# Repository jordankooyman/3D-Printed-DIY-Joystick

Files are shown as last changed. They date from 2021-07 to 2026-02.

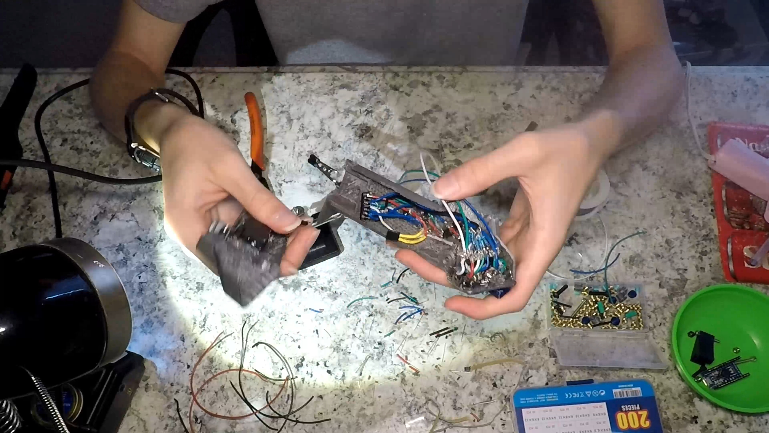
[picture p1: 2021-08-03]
Images/Pictures From Build Guide Video/Untitled_2.1.16.jpg

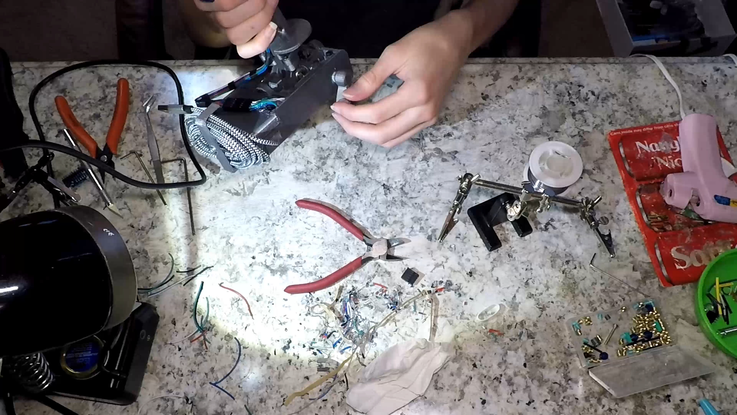
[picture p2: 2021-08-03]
Images/Pictures From Build Guide Video/Untitled_2.1.41.jpg

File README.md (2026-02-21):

# 3D-Printed DIY Joystick
A 3D-Printable Joystick for use with PC flight simulators
Throttle Joystick Side Videw

Updated!
New arduino code has been included in the code folder that should be much more reliable and easier to modify and work with.

This model uses hall-effect sensors for high accuracy inputs into flight simulators. The Joystick features 3 axes of movement (Pitch, Roll, and Yaw), and one potentiometer mounted in the base to act as a Throttle input (but it can be used as trim as well). 606 Bearings are used on the pitch and roll axes for smooth operation and longevity. A steel rod is used as the pivot point for the yaw axis. Due to the number of buttons included in the joystick (24), 3 8-bit shift registers are used to reduce the output wire count to a more reasonable number. Everything is connected to an Arduino Pro Micro, which uses an Atmega 32u4 processor, which is capable of handling USB communications without additional hardware or software. This means that although this joystick is custom-built, it is compatible with any PC that accepts USB Game Controllers (and maybe some consoles as well).

I have also created an optional Throttle-Assembly. To use it, a joystick can be mounted onto the sliding carriage on the Throttle-Assembly and a 3-pin-wire can be plugged into the joystick from the Throttle-Assembly, and a switch can be flipped on the joystick base to enable the external throttle input instead of the internal throttle input.

Overall, I spent about $175 on this project, but I had some of the parts on hand and I bought others in larger-than-necessary quantities. Depending on where and when your buy your parts  (and exactly what you intend to build), you overall cost will vary significantly.

-- This is NOT a beginner-friendly project as this is still an early prototype with some convoluted assembly --

# Credit Goes To:
Thingiverse user akaki for the original joystick model that I modified:		https://www.thingiverse.com/thing:4576634

Thingiverse user droftarts for their OpenSCAD pulley generator:				https://www.thingiverse.com/thing:16627

Thingiverse user Area51 for their GT2 Belt Clip:							https://www.thingiverse.com/thing:2354961

Matthew Heironimus for his Arduino Joystick library:						https://github.com/MHeironimus/ArduinoJoystickLibrary

Adafruit for their ADS11x5 Arduino Library which can be downloaded directly in the Arduino IDE

# Changes Made to Original Model
- The handle has been thinned drastically to allow for more space for the extra wires associated with 24 (instead of 6) buttons and 3 shift registers.

- The mounting pillar for the handle has been split with some wings added. The split allows the handle to be rotated in the yaw axis, and the wings allow for two arms to be mounted, with a spring in-between them to return the handle to 0 rotation.

- A hole has been cut in the bottom of the base to give additional clearance, as well as access, to the new yaw-axis hall-effect sensor.

- The front electronics section of the base has been doubled in length to give additional space for wiring as well as space for a 16-bit ADC (analog-to-digital converter) that is used in place of the 12-bit ADC built into the Arduino Pro Micro.

- 3 holes have been added to the front of the front cover peice to act as posts to wrap the usb cable around and to tie it in-place with. This is opposed to just wrapping the USB cable around the handle.

- All holes intended for M3 bolts have been enlarged to allow for Brass M3 Threaded inserts to be inserted to allow for better bolt pull-out resistance as well as increased longevity of the bolt threads.

- Most tolerances between parts increased to between 0.4mm and 0.6mm

- My Version D is a modification to akaki's Version C, so a number of my parts retain the Version C label as they have been changed minorly at most

# Code Configuration
The sample code is based on my right joystick code, which has one of the 4 hat switch inputs on the lower shift register. The reference code for the left joystick does not have this.
The same applies to the new V4.0 code as well. The new calibration process is very similiar to the old one, but it should be much more reliable and quicker.

# Print Settings
I used a 0.4mm Nozzle with PETG at 30% infill on most of the parts. The only exceptions are the Button Caps, which are so thin that a 0.2mm Nozzle is required, and the joystick left and right side, which are quite thin compared to the original and should probably be printed at around 60% to 80% infill.

Supports were enabled for all parts, but only touching the build plate. I used Cura's Tree Supports to reach most overhangs. Unless your support settings are tuned such that supports on top of printed parts peel off extremely easily, do not print supports on the parts, only on the build plate. Otherwise, you will likely need to use a rotary tool (such as a dremel) to remove them all.

I used Silver for most of the parts, with the Button Caps being printed in Translucent Aqua, and the trigger and Hat cover being printed in Translucent Glittery Dark Blue (called Starry Night).

# Joystick (Handle and Base) Bill of Materials
	1 Joystick:
	1 Arduino Pro Micro (Must have a ATmega 32u4 processor)(if pin headers are not already soldered in, I recommended soldering them to point up rather than down)
	1 ADS1115 (Optional: built in 12-bit ADC can be used instead)
	3 AH3503 Linear Hall-Effect Sensors
	1 15mm 10k 3 pin potentiometer with washer and nut
	24 10k Ohm Resistors (1 for each button, use a lower value is using active-low (button connects to ground) instead of active-high (button connects to VCC) button signals)
	2 4.7k Ohm Resistors (Optional: Only needed if using ADS1115 or similar board that uses I2C)
	3 74HC165 Parallel-to-Serial Shift Registers
	18 6mm*6mm Tactile Pushbutton Momentary Switches - Assorted button lengths
	1 SPDT Long Hinge Roller Arm Microswitch - Approximately 28mm*10mm*16mm
	1 10*10*9 6 pin 5-way Momentary Tactile Switch SMD (Optional) (A Nintendo Switch Replacement Joycon thumbstick might fit here instead (that would change the wiring fairly significantly, be aware)
	1 Micro USB to USB cable - Any length 4ft of longer
	1 5mm*65mm Steel Rod (Aluminum or Brass also acceptable)- Grind Flats as indicated in the 3D Model- Used as the Yaw-axis pivot
	2 M4*15 Socket-Head Bolt (Can be substituted for any M4 head variant)
	1 M4*15 Button-Head Bolt
	2 M4 Hex Nuts
	6 5mm*2mm round Neodymium magnets
	2 4pin*2pin Dupont-Style Connectors and assosiated crimpable pins (Precrimped wires can also be used) - Other connector styles can also be used
	2 M2*4mm Bolts (Optional: Only needed if installing external throttle input)
	17 Brass M3 Threaded Inserts - 6mm tall, 5mm diameter (use about 200 degrees C on soldering iron to press in)
	4 606 Bearings (any variant)
	1 3pin Dupont-Style Connector and 3 crimpable pins (Precrimped is also acceptable) - The pins and holes combination is arbitrary - (Optional: Only Needed if Throttle-Assembly is built)
	1 3 position slide switch - single pole (double pole also works) (Optional: Only Needed if Throttle-Assembly is built)
	Assorted M3 Bolts (6mm, 8mm, 10mm, 16mm, 25mm Recommended) Hex Socket Head recommended
	Assorted small extension springs (larger than pen springs, however)
	Pin headers for use with Arduino and ADS1115 (Optional)
	Wire of Assorted Colors (I used 22awg)
	Heatshrink of Assorted Sizes
	Thin Steel Sheet strips - Must be ferromagnetic (Can be obtained by cutting up the bottom of a Pringles can)
	5-minute Epoxy
	Isopropyl Alcohol
	Super Glue
	Disposable Rubber Gloves (Optional but recommended
	
	Rotary Tool (or some other way to cut steel (or your choosen metal shaft material))
	Mini Hot Glue Gun and Glue Sticks (Regular size also works, but not as easy to fit everywhere)
	Dupont-Style Crimping Tool
	Soldering Iron
	Tip for Soldering Iron that fits in the M3 inserts without sticking out the other end - expect to get plastic on this
	Wire Strippers (Optional, but highly recommended)
	Multimeter with continuinty testing (Optional, but highly recommended)
	~400g of filament
	
   # Printed Parts - Joystick
	Base (Version D):
		1 axis_for_ver_D v3  --  Print Flat
		1 base_cover  --  Print Front-Down
		1 Bottom  --  Print with wings down
		1 cable cap  --  Print Vertical, longest continuous side down
		1 cam_arm  --  Print Flat
		1 hinge_cam  --  Print Flat
		1 hinge_cam_slider_for_ver_C v3  --  Print Flat
		1 hinge_ver_D_-_606_bearings v3  --  Print Flat
		1 Mount Base  --  Print Bottom-Down
		1 Top  --  Print Tall with lengthwise hole facing up
		1 trim knob (Optional)
		1 Wire Storage Clip or Wire Storage Clip Hook (Optional)  --  Print Flat
		1 Yaw Rod Retention Clip  --  Print Flat
		2 Yaw Spring 2  --  Print Flat
		2 M4 Bearing Spacers  --  Print Flang-Down
	
	Handle:
		1 5-way button spacer (Optional)
		6 Button Cap Body - Print with 0.2mm Nozzle - Print Spares  --  Print Opening-Up
		12 Button Cap Face - Print with 0.2mm Nozzle - Print Spares  --  Print Opening-Up
		1 Face Plate  --  Print Rounded-Edge-Down
		1 joystick_grip_left_side v2 - with Left Side Handle Insert lined up, as seen in joystick grip left side filled.3mf  --  Print with hollow inside down
			- Mirror this part to make a left handle instead of a right handle
		1 joystick_grip_right_side v2  --  Print with hollow inside down
			- Mirror this part to make a left handle instead of a right handle
		1 Stadium Hat or Trim Hat  --  Print with short stem down
		1 trigger  --  Print Side-Down

# Throttle-Assembly Bill of Materials: - Requires Joystick to Use
	2 8mm*330mm Steel Rods - must be perfectly straight
	4 8mm*15mm*45mm Linear Bearings (shorter bearings are also compatible, and only 2 are necessary, but Mount will need to be redesigned)
	4 606 Bearings (any variant)
	1 15mm 10k 3 pin potentiometer with washer and nut
	3 3mm*300mm Steel Rods (other metals also acceptable) (Optional: Recommended, but not needed if base is printed in 2 pieces)
	1 1m GT2 Timing Belt
	16 Brass M3 Threaded Inserts - 6mm tall, 5mm diameter (use about 200 degrees C on soldering iron to press in)
	2 M3*35mm Bolts
	10 M3*10mm Bolts
	10 M3 Washers
	12 5mm*2mm round Neodymium magnets
	8 small zipties
	1 70mm Closed Loop MXL Belt - Can be subsituted for another type of belt, ideally a closed loop of about this length or slightly longer
	Masking tape
	5 minute epoxy
	Isopropyl Alcohol
	Grease (for the linear bearings)
	Disposable Rubber Gloves (not necessary, but recommended)
	
	Rotary tool (or some other way to cut the 3mm metal rods to 80mm lengths (7 are needed))
	Mini Hot Glue Gun and Glue Sticks (Regular size also works, but not as easy to fit everywhere)
	Dupont-Style Crimping Tool
	Soldering Iron
	Wire Strippers (Optional, but highly recommended)
	Multimeter with continuinty testing (Optional, but highly recommended)
	Tip for Soldering Iron that fits in the M3 inserts without sticking out the other end - expect to get plastic on this
	~600g of filament
	
   # Printed Parts - Throttle Assembly
	Fit Test:
		1 Base - Ensure the 8mm*330mm Steel Rods fit  --  Print with hole horizontal
		1 Mount - Ensure the 8mm*15mm*45mm Linear Bearings Fit
	Build:
		4 Adjustable Bearing Pillow Block v2  --  Print Side-Down
		1 Adjustable Pot Mount  --  Print Potentiometer-Hole-Horizontal
		1 Base 1  --  Print Flat
		1 Base 2  --  Print Flat
		1 Cover 1  --  Print Flat
		1 Cover 2  --  Print Flat
		1 Belt Pin Spacer  --  Print Flat
		1 Drive Axle  --  Print Flat-Side-Down
		1 Idler Axle (lower into print bed to create a flat side for better printing reliability)  --  Print Flat
		1 Mount  --  Print Top-Down
		1 Mount Side  --  Print Tab-Up
  	Imported Parts:
		2 X-Belt-Holder-Thin-GT2  --  Print Vertical
		2 GT2 2mm 6mm Wide 50 Tooth Idler M4 Shaft  (Sample - Generate and Test your own to ensure they fit your belt and Drive Axle and Idler Axle)  --  Print with teeth vertical
		1 40T 2.75mm MXL Pulley for Pot  (Sample - Generate and Test your own to ensure they fit your belt and potentiometer)  --  Print with teeth vertical
		1 20T 2.75mm MXL Pulley  (Sample - Generate and Test your own to ensure they fit your belt and Drive Axle)  --  Print with teeth vertical
				Use the OpenSCAD pulley generator for these 4 pulleys, using about the same size for all and the 2:1 gear ratio for the potentiometer. More drastic changes will require the model to be reworked.

# Build Guides:
Check out the videos I made for the major steps of the build as well as tips while building.

Check out the BuildSteps.md file for more step-by-step instructions without pictures. Reference the video to see pictures of all major steps.

Check out my Calibration Guide video to learn how to calibrate your own joystick using the code I wrote. Some aspects of the calibration process has been updated since the video, check the comments at the top of the sample code for details.
	
* Use the Sample Code provided and modify as needed to test and program your Arduino Pro Micro(s) for your joystick(s)
	
	* My Joysticks' code is included for reference purposes only and is not written to be modified as easily, nor is as well documented

# Project Videos:
Project Overview:													https://youtu.be/e_4dbrvhuwY

Chair Mounting Solution and Throttle-Assembly Build Explanation:	https://youtu.be/rQSjNkJ6G9A

Joystick Approximate Build Guide:									https://youtu.be/sCnEafJgWUY

Joystick Calibration Guide (Outdated):							https://youtu.be/MGDJYMHP4_0

Full Build Timelapse (5x Real Speed):								https://youtu.be/Amg51pNDD08

# Elite Dangerous Sample Gameplay Videos Using My Joysticks:

Bounty Hunting:									https://youtu.be/YqyOV4E18Ls
	
Mining:											https://youtu.be/bz7r8q-hPg0
	
Traveling Between Systems:						https://youtu.be/_PC3MqTWRCQ
	
- Vulture Ship Outfitting (bounty hunting):		https://youtu.be/YhuHz4nPciU
	
- Anaconda Ship Outfitting (mining):			https://youtu.be/gqCUKOQVyXI

# Future Ideas:
- Redesign the handle from scratch with a slightly increased diameter, larger face plate, and reworked thumb section for more wiring space and more strength.

- Add more buttons to the handle by adding a fourth shift registers

- Connecting all shift registers to one communications set instead of two seperate communications sets (this requires a decoupling capacitor to function)

- [Optional] Change the hat switch out for a Joycon thumbstick - likely connected to the Arduino Pro Micro's 12-bit ADC (should need two inputs)

- Improve the cable storage technique 

- Design a standalone handle with some buttons and an Arduino Pro Micro to mount on the throttle assembly and use it without a Joystick connected

- Design a function pedal unit that uses an Arduino Pro Micro - or hooks into the external potentiometer connector on a joystick - must be stable enough to use - anchor to chair?

- Rework the front cover part to clip in instead of glue in

- Design a custom PCB(s) for the face buttons - include the option for a few different layouts (such as using a joycon part over hat switch) - potentially use a large connector to join all buttons onto handle PCB and include shift registers there instead(?)

- Design a custom PCB for the handle - likely using short extension wires for each button

- Use a 10K Ohm Resistor Array (9 pin, bussed) for each shift register on a PCB (and try to avoid SMD components so all can be hand soldered easily)

- Design a custom PCB for the Joystick Base electronics section (with the ability to use an auxiliary ADC, or use internal ADC (and trim board shorter??))

- Improve the ribbon cable that joins the joystick handle and base (more flexibility and durability)

- Improve the external throttle connection location (as well as the slide switch)

- Revise throttle sensing mechanism to be more robust and simpler while maintaining long travel and absolute positioning with 0.1mm accuracy

- Improve Yaw axis mounting (move inside handle)

- Revise Yaw return-to-center with pair of torsion springs inside, longer fixed shaft with bearings, and a printed part on top with set screw to attach top bearing and springs and magnet to

- Simplify Build Guide and add a picture to each step

- Redesign code architecture to allow for dynamic callibrations to be generated and stored using a PC utility

- Improve resolution of hall sensor readings to allow for smoother movement when range is cropped

- Improve hall sensor mounting and wiring on pitch/roll axes

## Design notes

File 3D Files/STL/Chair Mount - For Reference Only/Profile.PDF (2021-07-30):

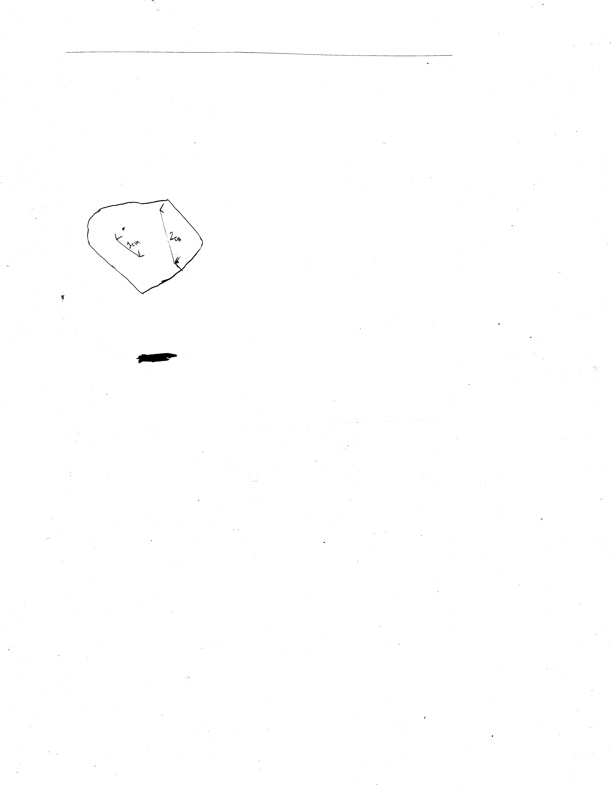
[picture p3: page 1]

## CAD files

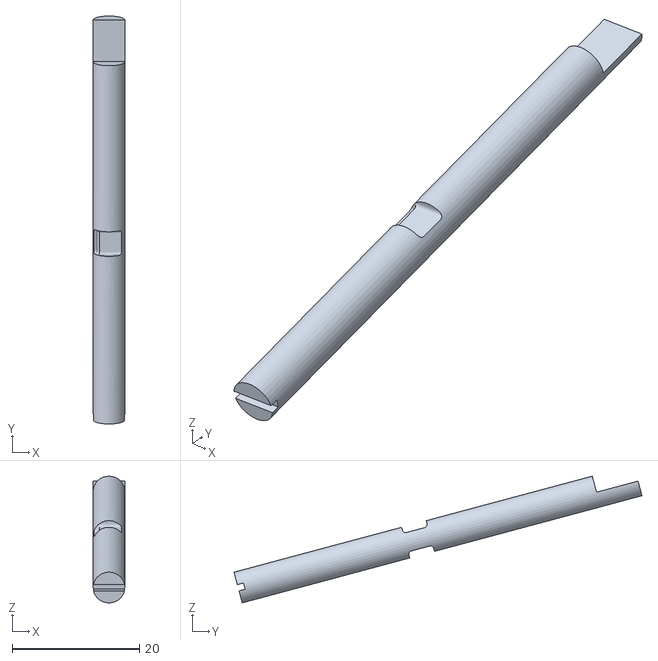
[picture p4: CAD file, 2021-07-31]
3D Files/STL/Base - Version D/Yaw Shaft (Steel).stl
4.99 x 64.1 x 19.9

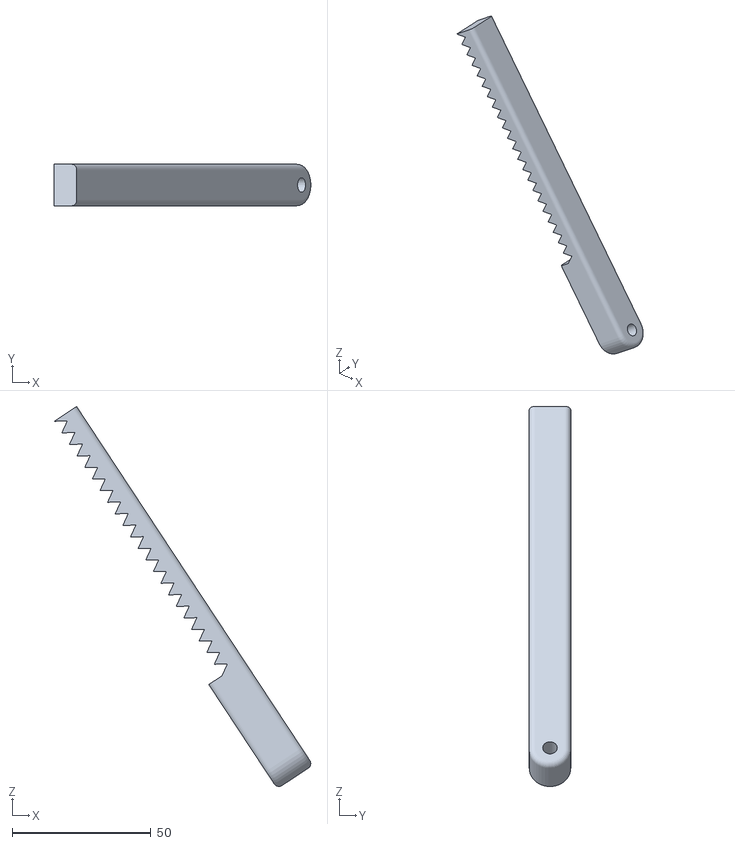
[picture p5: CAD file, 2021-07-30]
3D Files/STL/Chair Mount - For Reference Only/Long Support Arm Top.stl
92.6 x 15.0 x 137.1

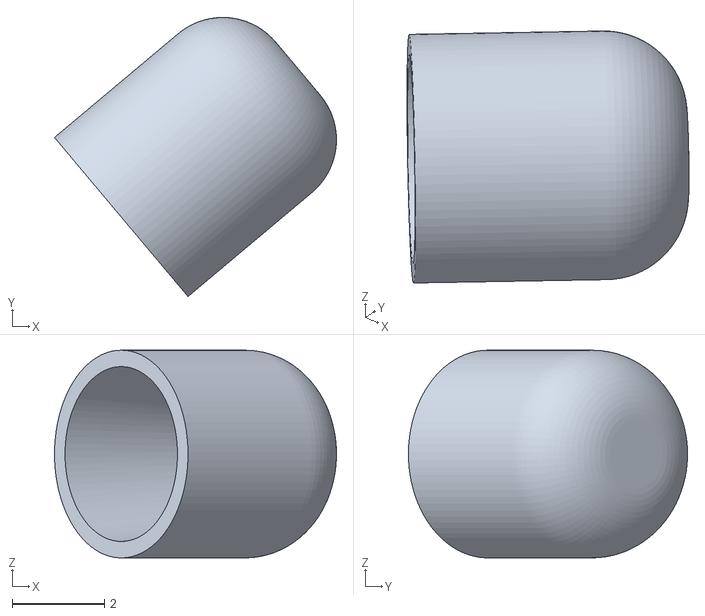
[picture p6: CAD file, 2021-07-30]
3D Files/STL/Handle/Button Cap Face.stl
6.11 x 6.05 x 4.50

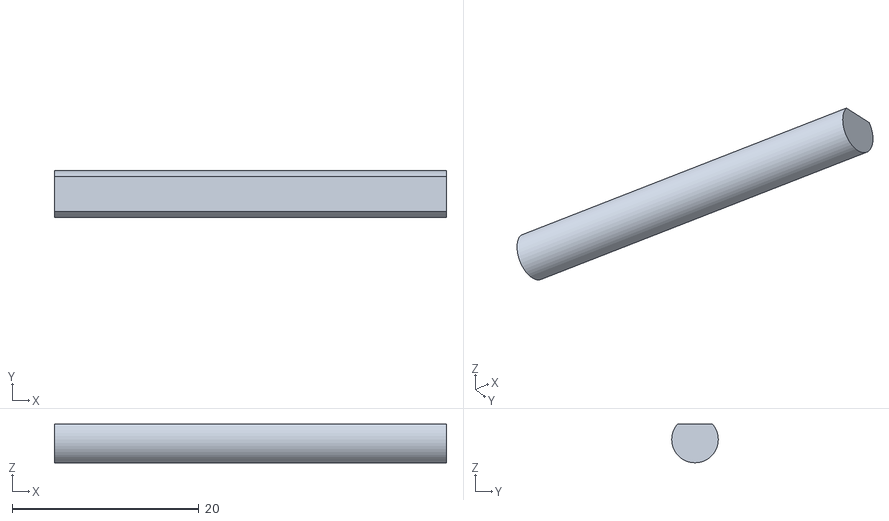
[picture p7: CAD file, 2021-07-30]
3D Files/STL/Throttle Add-On 2.0/Drive Axle.stl
42.0 x 5.00 x 4.14

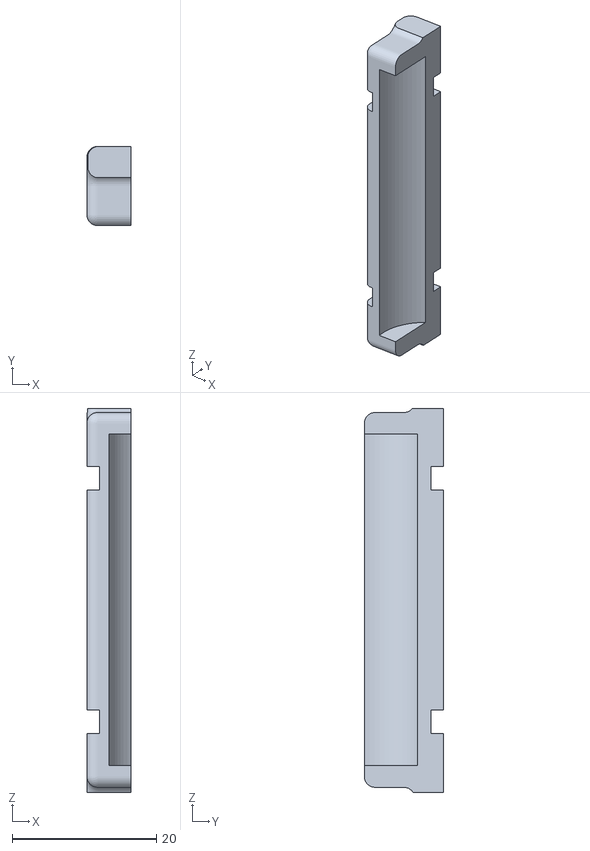
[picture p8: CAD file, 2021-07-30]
3D Files/STL/Throttle Add-On 2.0/Fit Test/Mount.stl
6.14 x 11.0 x 53.3

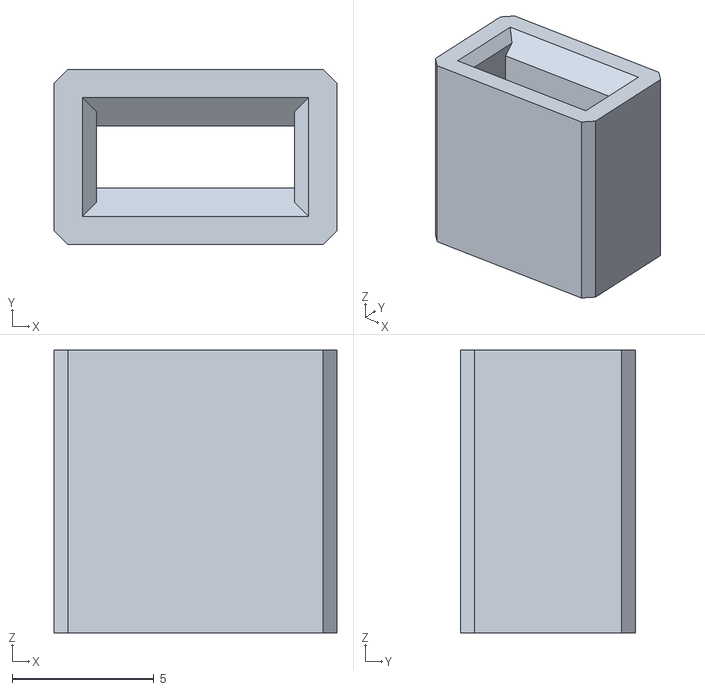
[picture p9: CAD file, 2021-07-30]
3D Files/STL/Throttle Add-On 2.0/Imported Parts - Sample Only/X-Belt-Holder-Thin-GT2.stl
10.0 x 6.20 x 10.0

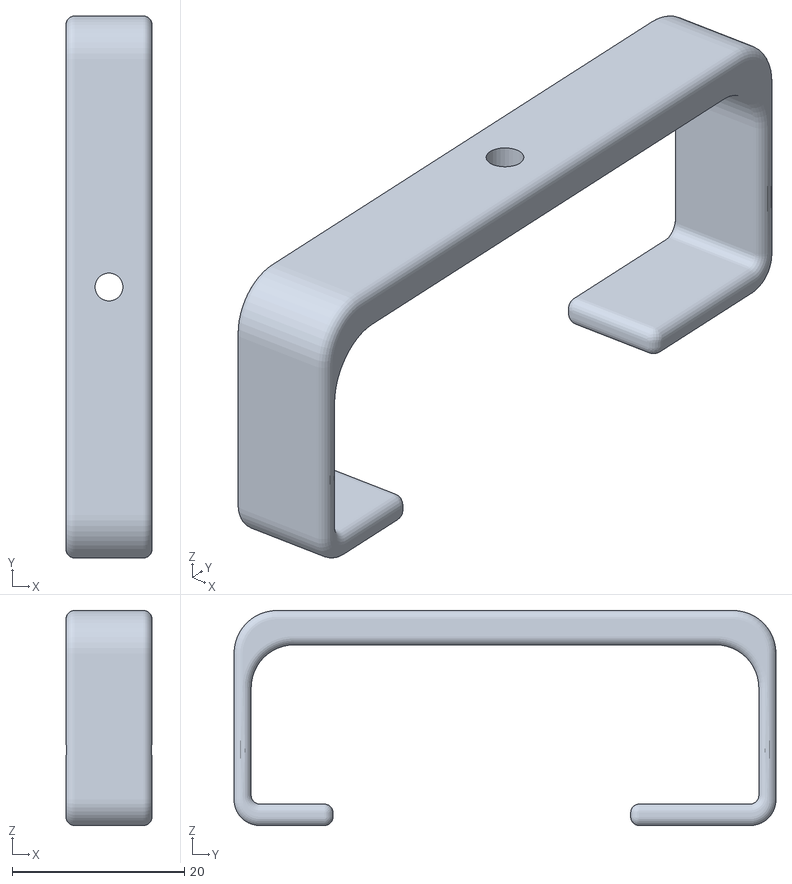
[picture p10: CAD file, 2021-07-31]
3D Files/STL/Base - Version D/Wire Storage Clip Hook.stl
10.0 x 63.0 x 25.0

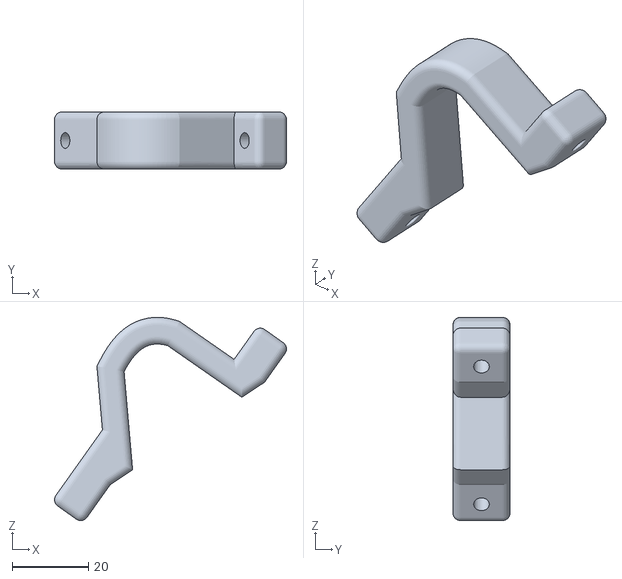
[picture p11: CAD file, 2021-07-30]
3D Files/STL/Chair Mount - For Reference Only/Left Clamp Back Top.stl
60.9 x 15.0 x 53.3

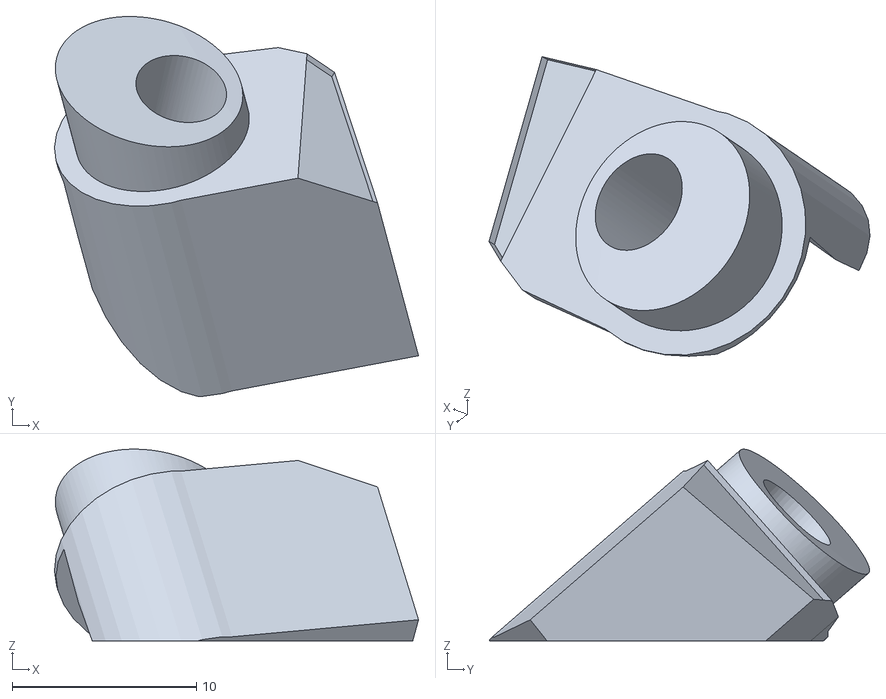
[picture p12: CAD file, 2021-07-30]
3D Files/STL/Handle/Left Side Handle Insert.stl
19.8 x 20.6 x 10.4

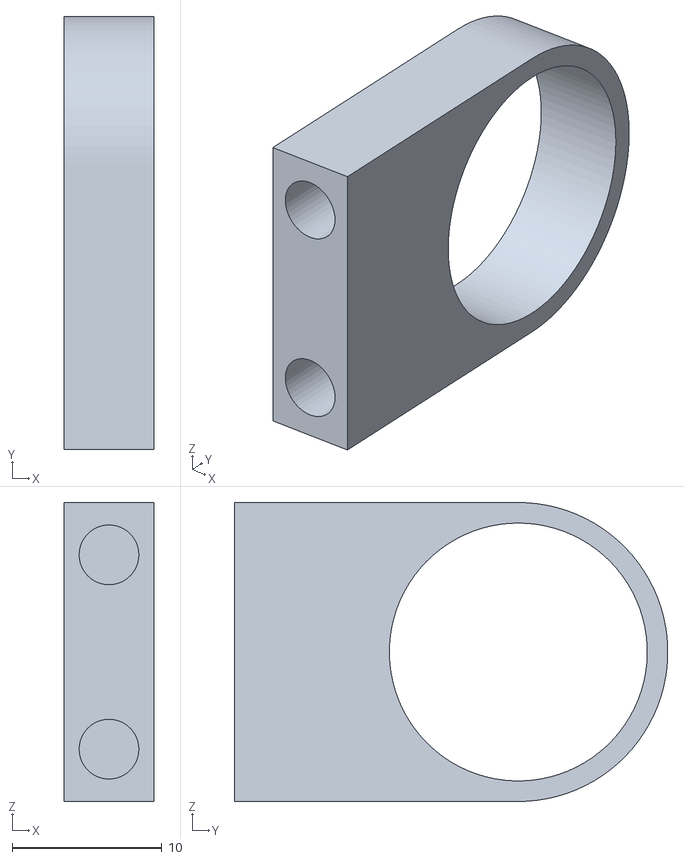
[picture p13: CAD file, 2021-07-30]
3D Files/STL/Throttle Add-On 2.0/Adjustable Bearing Pillow Block v2.stl
6.00 x 29.0 x 20.0

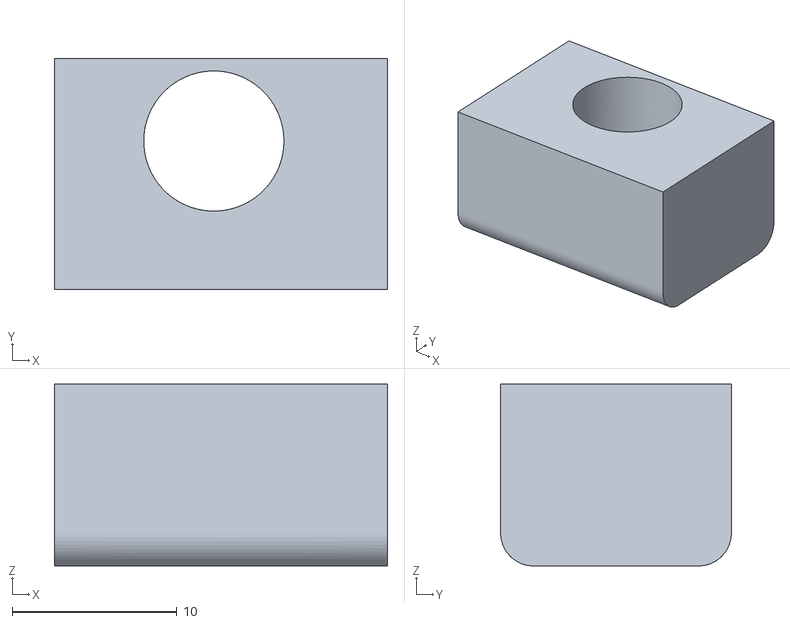
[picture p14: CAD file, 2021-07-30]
3D Files/STL/Throttle Add-On 2.0/Fit Test/Base.stl
20.2 x 14.0 x 11.0

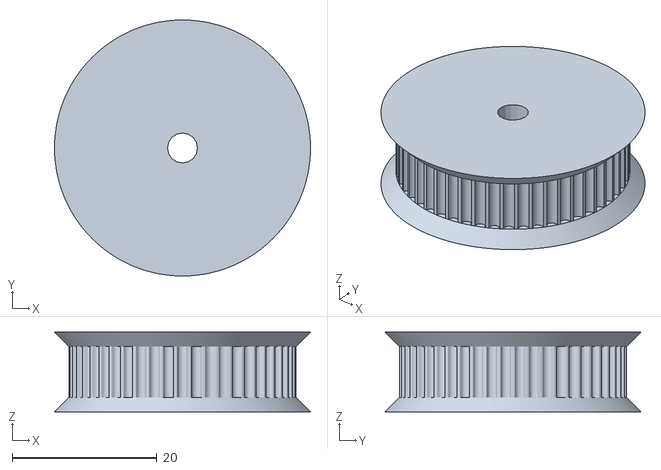
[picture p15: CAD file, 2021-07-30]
3D Files/STL/Throttle Add-On 2.0/Imported Parts - Sample Only/GT2 2mm 6mm Wide 50 Tooth Idler M4 Shaft.stl
35.3 x 35.3 x 11.0

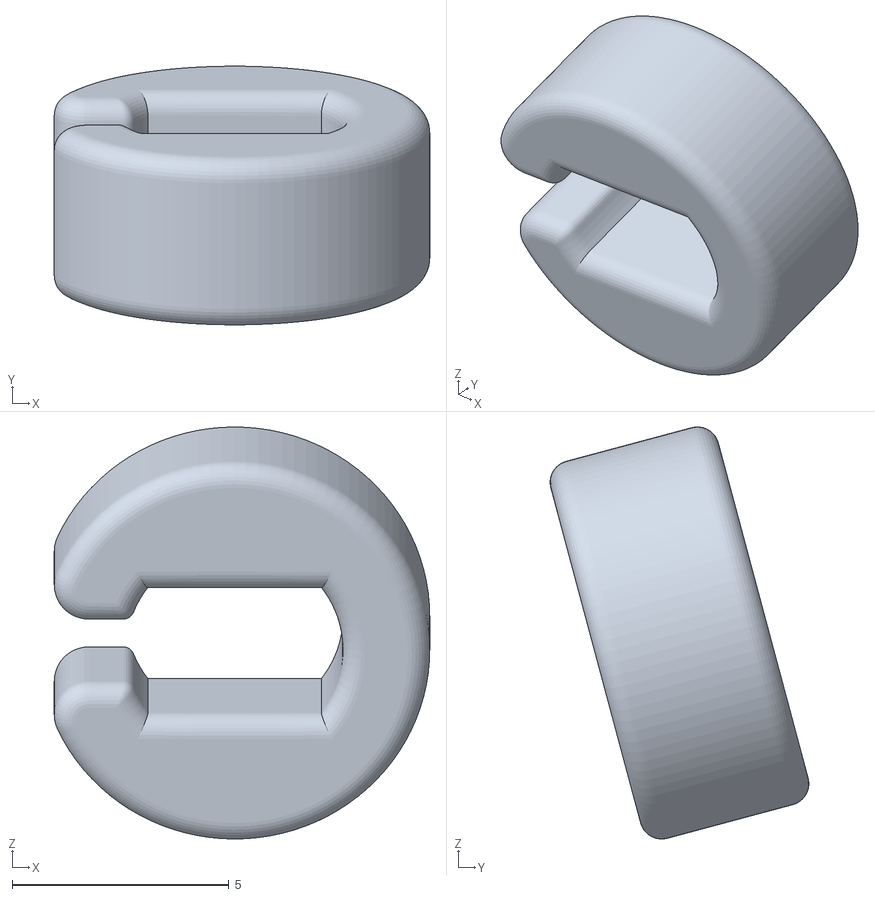
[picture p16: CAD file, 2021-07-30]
3D Files/STL/Base - Version D/Yaw Rod Retention Clip.stl
8.66 x 5.96 x 9.50

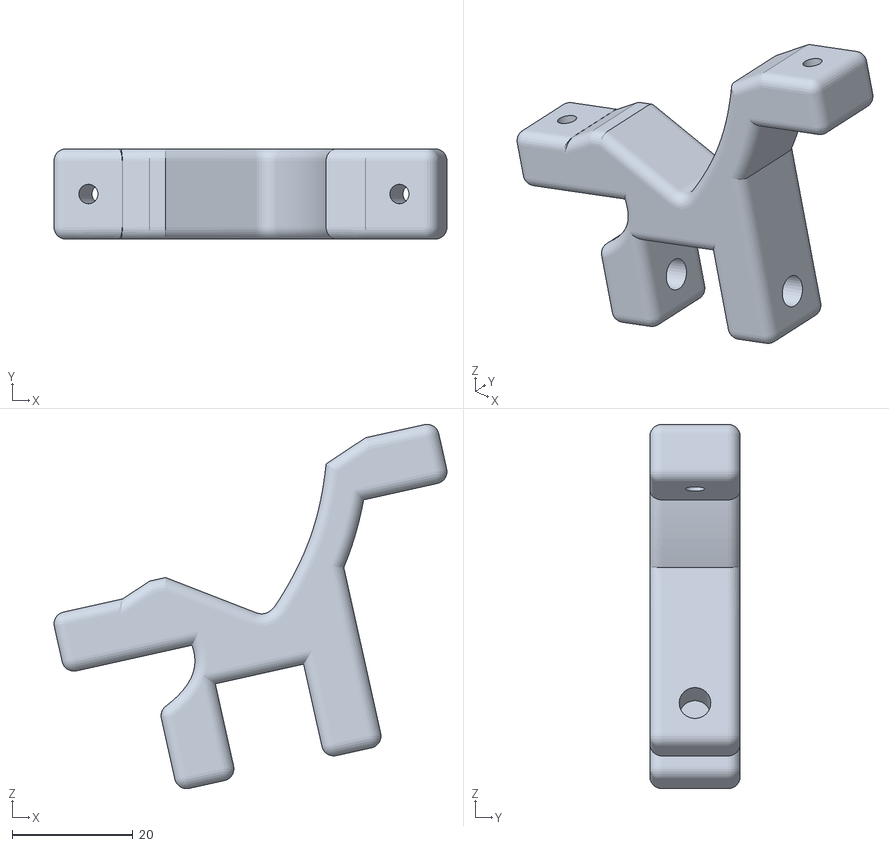
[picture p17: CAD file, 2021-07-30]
3D Files/STL/Chair Mount - For Reference Only/Right Top Front Clamp.stl
65.2 x 15.0 x 60.5

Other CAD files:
3D Files/STL/Handle/5-way button spacer.stl
3D Files/STL/Throttle Add-On 2.0/Cover 1.stl
3D Files/STL/Throttle Add-On 2.0/Imported Parts - Sample Only/40T 2.75mm MXL Pulley for Pot.stl
3D Files/STL/Base - Version D/cable cap.stl
3D Files/Fusion 360/Custom Chair Mount (Reference Only).f3d
3D Files/STL/Base - Version D/Bottom.stl
3D Files/STL/Base - Version D/M4 Bearing Spacer.stl
3D Files/STL/Base - Version D/Mount Base.stl
3D Files/STL/Base - Version D/Top.stl
3D Files/STL/Base - Version D/Wire Storage Clip.stl
3D Files/STL/Base - Version D/Yaw Spring 2.stl
3D Files/STL/Base - Version D/axis_for_ver_D v3.stl
3D Files/STL/Base - Version D/base_cover.stl
3D Files/STL/Base - Version D/cam_arm.stl
3D Files/STL/Base - Version D/hinge_cam.stl
3D Files/STL/Base - Version D/hinge_cam_slider_for_ver_C v3.stl
3D Files/STL/Base - Version D/hinge_ver_D_-_606_bearings v3.stl
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

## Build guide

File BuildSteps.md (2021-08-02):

This guide assumes you are building what I have built (including active-high button signaling)

# Joystick Build Instructions
Handle:

- Choose 12 6mm*6mm push buttons for the face panel (differing lengths can be used to make certain buttons stand out) and fit one button cap (shorter variant) to each one. If one does not stay on, a small dab of hot glue will help.

- Check the fit of the hat switch with hat included in the face plate. All 5 clicks should be accessible. If they are not, either change the spacing between the hat switch and face plate, or enlarge the hole. Once fit is good, glue in the spacer (if used) with a thin glue such as super glue, then continue.

- Arrange the 12 buttons in the face panel assembly such that one side of each button forms a common link with the buttons adjacent (the longer the chains, the less wires will be needed to join these together on the common side). Check which sides of the button are joined and which are only connected when the button is pressed (there are typically 4 pins, with 2 bars separating the 4 pins into 2 sets, and each set is joined together). Use hot glue to fill the gaps between the buttons to hold everything in place. Ensure enough space is left for the hat switch (or the spacer is glued in).

- Bridge one side of all the push buttons, using short lengths of red wire where necessary to form the common 5V line.

- Test the fit of this assembly in the both sides of the handle. Make any adjustments necessary for a good fit when the handle halves are held closed.

- Solder ~2 inch (50mm) lengths of different colored wires (not red or black) to all the buttons, one to each button. Ensure none of them are on the common side.

- Prepare the hat switch by tinning the 6 leads, measuring out and cutting 6 wires (1 color: ~8 inch (~250mm),4 colors: ~2.5 inch (~65mm), red: ~1 inch (~25mm)). Connect the red wire to the common pin, the long wire to the center click pin, and the remaining wires to the remaining pins. Solder the wires such that each wire runs across the back of the hat switch, forming a V of inter-woven wires.

- Place the hat switch in its position and ensure it still fits with hat cover on. Then tack in with a small amount of hot glue before putting globs of hot glue all around it to hold it in place (ensure it can still move freely before and after the globs of hot glue are added. If it cannot, remove the hot glue by using isopropyl alcohol (pour small amounts around the edge of the glob and peel the hot glue off).

- Prepare 2 SN74HC165 Shift Registers by tinning all the leads that are needed (VCC, GND, 8 Inputs, Clock, Enable, Load Data, Serial Output, and Serial Input (only this one on 1 of the 2)). Find a wiring diagram online to determine which pins are what.

- Separate the 17 wires from the buttons into 5 groups: 1 group of 1 wire (the long wire from the hat switch) and 4 groups of 4 wires (try to keep each group to one line of buttons as best as possible and filling in gaps with the hat switch leads, as this makes soldering to the shift registers, and later debugging any issues, much easier). Trim each group of wires to a common length, ensuring they are all long enough to connect to an input pin on a shift register placed above it, upside down, strip ~3mm off each wire, and tin the end of each wire.

-  Continue by soldering in both shift registers to the button leads. Start with the middle 2 groups, connecting one to each shift register, then solder the outer 2 groups of wires to the outward facing inputs on each shift register.

- Connect a short length of red wire from the VCC input of each shift register to somewhere along the common path on the buttons.

- Cut a large diameter piece of heat shrink (ideally about 0.875 inches (~20mm) tall when flattened) to a length of ~1.5 inches (~30mm) and place between the 2 shift registers to prevent short circuits (do not unfold to 1 layer unless you do not have a large enough piece of heat shrink tubing).

- Test the fit of this assembly in the both sides of the handle. Make any adjustments necessary for a good fit when the handle halves are held closed.

- Prepare 16 10k registers by trimming one side to ~10mm and tinning the shortened leads.

- Solder the shortened end of each resistor to one input pin for all input pins on all shift registers. 

- Then do a half twist of all the long resistor leads above each shift register and separate out and bend one lead to go down to the GND pin and one lead to go to the Enable pin on each shift register, soldering them in place. 

- Then solder each ball of resistor leads together with a large blob of solder, followed by trimming all excess resistor leads. Then solder in a short length of black wire between the two solder balls.

- Connect the serial output of one shift register to the serial input of the other shift register (the one with that lead already tinned, preferably) with a short length of wire running along the bottom (now top) of the IC casing, staying under the resistors.

- Prepare 3 ~6 inch (~150mm) lengths of colored wire and connect one to each of the following pins on the shift register that has the serial input used: Load Data, Serial Output, and Clock. 

- Then, using a short length of the same colors of wire, connect the corresponding pins on the other shift register to this shift register and the pins with the long wires connected to it. 

- Write down which color of wire is connected to which pin.

- Connect a ~3 inch (~80mm) red wire to the common section of the buttons and a ~6 inch (~130mm) black wire to one of the solder balls.

- Test the fit of this assembly in the both sides of the handle. Make any adjustments necessary for a good fit when the handle halves are held closed.

- Test that everything is working by connecting all 6 wires to an Arduino Pro Micro (ideally using a single pin header) (red to VCC, black to GND, and the 4 colors to any I/O pin). Using the shift register test Sample code, test that every button works properly by updating the pin numbers to reflect which pins are used. Additionally, test this assembly again while it is pressed into both halves of the handle.

	- If a button is not giving an input, make sure the wire corresponding to has not come loose. If a button is showing as clicking multiple buttons, verify it is not shorting against other pins. If a button is showing as always on, make sure the wire for that button is not connected to the common side.

- Once everything is verified to be working, set this button panel assembly aside to begin working on the handle assembly.

- Begin by selecting 6 6mm*6mm push buttons of varying lengths, one for each hole in the primary side of the handle (left for right joystick, or right for left joystick). Ensure that each button can be clicked with a button cap (longer variant) pressed or glued to the end.

- Continue by tinning all 4 leads of all 6 buttons, then soldering a common red wire between all 6 (ensuring it is the proper length to reach each button when all are installed) and a colored wire that is long enough to reach slightly into the indent used for mounting the handle to the base. Additionally, ensure that the colored wires are not connected to or shorting against the common wire in any location (a continuity check works well).

- Solder an additional ~3 inch (~75mm) red wire to the common side of the furthest down button. Repeat this step for the button just above that (lowest) button.

- Once all the wires are soldered to all 6 handle buttons and all the buttons are fitted into the handle, apply a generous sized glob to the back of each button to hold it in place. Once the glue has cooled, ensure all buttons can still be pressed easily (if not, try twisting them or dropping a small amount of isopropyl alcohol down the button shaft and twisting it).

- Set the primary handle side aside to work on the secondary side.

- Prepare the large microswitch by soldering 2 ~2 inch (~25mm) wires to it, one to the common (this is ideally red), and a color to the normally open pin on the microswitch.

- Using the trigger, a long M3 Bolt (nut optional but useful), and the microswitch, determine the position of the microswitch such that the trigger can easily click the microswitch, the spring of the microswitch pushes the trigger back out entirely, and when the trigger is not pressed, the microswitch is also not clicked. Once that position has been found, use hot glue to hold the microswitch in position by applying hot glue around the 3 edges that do not have the button and lever arm (also, ensure that the hot glue does not impede the movement of the lever arm in any way).

- Then, bend the two wires soldered to the microswitch 180 degrees to come back alongside the side of the microswitch, trim the two wires to be even (in the bent shape) about 10mm from the upper edge (the side the lever arm overhangs) of the microswitch, place a short length of heat shrink tubing of appropriate size on each wire, slide the heat shrink as far down as possible, solder the two wires to a 2-pin pin header (or some other 2 pin connector), and insulate the solder joints with the heat shrink tubing. A small dab of hot glue can be used on one of the wires to help keep them bent around the microswitch, just ensure the connector has enough freedom of movement to reach to the other side of the joystick handle when closed up (with some extra movement if possible, as this makes final assembly and maintenance much easier).

- Set aside the secondary handle side and return to working on the primary handle side

- Now prepare the third shift register by tinning the pins being used (8 inputs, Clock, Enable, Load Data, Serial Output).

- Next, using the shift register (again, with pins pointing up the handle)  as reference, trim all wires (excluding the further up red wire) to be about ~5mm to ~10mm longer than necessary to connect to an appropriate pin (either input of VCC). Tin the wires and solder all wires in place. There should be 2 unused input pins, preferably on the outward facing side of the shift register.

- Now, using the secondary side as reference, bend the extra red wire from the primary side around until in lines up with the connector from the trigger microswitch, trimming off excess if needed (ensure some wire is left to allow for movement). Then, setting the secondary side to the side again, measure out a length of colored wire to reach from the end of the red wire down to an available shift register pin, giving extra length to follow any bends in the red wire and to reach the shift register in the flattest possible path. Then prepare the end of the red wire and both ends of the colored wire for soldering by stripping them and tinning them, as well as putting short lengths of heat shrink tubing on both.

- Solder the other end of the 2-pin pin header (used with the microswitch) to the red wire and colored wire, then slide up and shrink the heat shrink tubing. Additionally, solder the other end of the colored wire to an input pin on the shift register.

- Prepare 8 more 10k registers by trimming one side to ~10mm and tinning the shortened leads.

- Solder one resistor to each input pin, just as was done on the face button assembly. Then join the long leads in a ball using a half twist and bend one lead to the GND input and one lead to the Enable pin, soldering them in place. Then solder the resistor ball together and trim the excess leads.

- Ensure the shift register can fit inside the handle when both halves are pressed closed. Also ensure the microswitch connectors align and do not interfere with anything when connected and the handle is closed.

- Next, test the fit of the face button assembly, and if everything still fits and works, use a generous amount (half of a mini stick approximately) of hot glue (while still working fast) across the top section where this assembly fits in the primary side of the handle to glue the face button assembly into place.

- Once cooled, desolder the pin header from the wires and run the 17th button wire down the handle, keeping it as low-profile as possible, to the shift register. Then trim the wire to the appropriate length to reach the 1 remaining input pin. Then solder in place.

-  Next, trim the red wire from the button assembly to be long enough to reach one of the red wires connecting all the buttons together. Strip a short section of insulation off of both red wires, tin them, and solder together. Ensure all buttons are still connected together on the common side.

- Then, run the black wire down the handle to connect to the solder ball above the bottom of the third shift register, trimming to length (again using the lowest profile path possible), and soldering in place.

- Now, run the 3 communications wires from the face button assembly down the handle, rearranging wires where necessary to ensure it can fit under the microswitch when the handle is closed (check the fit now). 

- Then, measure out two lengths of 4 sets of wires (ideally ribbon cable with a red wire on one set of 4 and a black wire on the other set of 4, but any ribbon cable will do). One set must reach up into the joystick to go about ~1 inch (~25mm) past the end of the wires for the face button assembly. The other set must reach up into the joystick handle to go to the handle shift register. Both should reach out ~5 inches (~120mm).

- Next, solder one set of wires to the 3 communications wires from the face assembly (again writing down which color is which). Solder the fourth wire to the common 5V line.

- Solder the other set of wires to the Clock, Serial Output, and Load Data pins on the shift register (again writing down which color is which), and connecting the fourth wire to the solder ball above the bottom of the lower shift register.

- Now, connect all the wires up to the Arduino and test using the shift register code once again. Debug where needed.

- Once every button is verified to be working, use hot glue to tack down the wires and the shift register. Use a large blob to keep the wires that run out of the handle from being pulled out further (include a little slack on the inside if possible).

- Test that everything is still working. Debug where needed.

- Join the two halves of the handle assembly together using 3 M3 bolts and nuts. The bolt the trigger pivots on cannot be tightened too much, as it causes the trigger to bind (tighten it until the trigger does not spring back out, then slowly loosen until it pops out, then add another quarter turn of looseness). The other bolt near the top should be tightened first, then the trigger, then the one near the bottom of the handle.

- Once the handle is entirely closed up, test to make sure every button still works as expected. Debug where needed.

- Once the handle is fully closed and every button still works, it can be set aside.

Base:

- Begin by removing any supports still on the printed models.

- Use a drill to sand down axis_for_ver_D v3 until it fits easily through a 606 bearing, but not so far that it wobbles.

- Fit the 4 606 bearings, 2 in the Mount Base, 2 in hinge_ver_D_-_606_bearings v3. If the bearings are tight, a light sanding (rotary tool recommended) of the plastic may be necessary. If the part cannot be pressed in easily, you risk fracturing the part by pushing harder. If the fit is loose, a little bit of 5 minute epoxy around the edges can hold them in place. Just make sure that if you glue it, they can still spin freely and that they are still aligned (use a long rod through both to ensure alignment).

- Cut and grind the 5mm shaft to match Yaw Shaft (Steel) model if not already done so. Ensure the Yaw Rid Retention Clip can fit over the center flat section. If not, the lips of the printed part can be trimmed or the rod can be thinned more (just do not go so far that it bends easily)

- Next, using the soldering iron and a tip that fits in your M3 brass inserts without sticking out the other end, press an insert into all of the following:
	- 4 on the bottom of Mount Base
	
	- 1 in the corner on the top of Mount Base
	
	- 3 into both Yaw Spring 2 parts (all on the same side)
	
	- 2 into Top (the upper (the large hole faces down) one must be quite deep as a M3*6mm bolt needs to sit flush with the surface of the part there, use the flat end of the yaw axis shaft to ensure it is not too deep).
	
	- 1 into Bottom
	
	- 3 into the front of base_cover (Optional, only if using the front wire storage solution)
	
- Using an M3 bolt, clean out the squeezed-out plastic from every insert accessible from both ends.

- Drill out the following parts using a drill bit that is just a little too large for the hole:
	- Main yaw axis shaft in Top and Bottom - Some brass may also be drilled out from Top.
		
	- The upper hole for Top, must be large enough to fit an M3 bolt head, drill down to brass insert.
		
	- Enlarge the hole to the left of the bearing when looking from the front cover side on Mount Base to fit an M4 bolt threaded into the plastic (if enlarged too far, use an M5 bolt instead or use an M3 bolt with another threaded insert)
	
- Continue by preparing the potentiometer. Cut a red, black, and colored wire to ~7 inches (~180mm), and connect the colored wire to the middle pin. Connect the remaining 2 wires to the outer 2 pins of the potentiometer.

- Fit the potentiometer into the Mount Base in the single large hole in the main cavity. The shaft should be pointing out of the assembly. Use a washer and nut that should be included with the potentiometer to secure it in place as tightly as possible. There should be a locater pin on the potentiometer that should align with a small secondary hole above the main hole for the potentiometer. Run the 3 wires from the potentiometer into the front electronics area, using the cutout on that side of the divider.

- Prepare the 3 AH3503 Hall Effect Sensors by soldering ~10 inch (~255mm) black, red, and colored wires to their leads (research online for the pinout). Add a piece of heat shrink over all 3 leads of all 3 sensors.

- Select one sensor and bend the leads 90 degrees such that the beveled face of the sensor is facing up when the wires are held vertical. Using super glue or 5 minute epoxy, glue the sensor to the small post in the main cavity of Mount Base with the leads/wires running down the vertical face and going towards the cutout on the left (when looking at it from the electronics section).

- Using 5 minute epoxy, glue 2 neodymium magnets into the small cavity on the bottom of hinge_ver_D_-_606_bearings v3. Before using glue, check the fit of the magnets. The magnets must have opposite poles facing each other when glued in (such that they are attracting (NOT repelling) each other).

- Take 1 strip of thin steel sheet and bend into a U shape large enough that 1 neodymium magnet can go an the inside of either tab (also touching the bottom of the bracket) and a hall effect sensor can fit in between and has enough space to spin without hitting anything. The magnets must be affixed such that they are attracting (NOT repelling) each other. Use 5 minute epoxy to glue the magnets in position after cleaning the magnets and steel strip with isopropyl alcohol. Repeat this step to make a second magnet bracket.

- Also use 5 minute epoxy to affix 1 or 2 washers over all 4 M3 threaded inserts on the bottom of Mount Base. These will act as spacers when the joystick is mounted to a mounting plate and prevent the yaw axis hall effect sensor from rubbing on anything and getting damaged or unglued.

- After the epoxy has set on both magnet brackets, the excess steel (and sharp edges) can be trimmed to match the profile of the round magnets.

- Next, fit the steel shaft through Bottom and align the double flat section in the middle with the square cutout in the printed part, the flat end should extend out from the side with the wings. Fit the Yaw Rod Retention Clip over the steel shaft (if it is loose, affix to the shaft using a small amount of super glue (ensure it does not glue anything else together!)).

- Then, fit Top onto the protruding section of the shaft, aligning the flat spot with the location of the inset M3 bolt. After pushing the shaft up (if it can move up/down), secure Top to it using the inset M3 bolt. Once fully tightened, the head of the M3 bolt should be flush with the outside edge of Top (if it protrudes slightly, (< 2mm), this is acceptable).

- Next, fit 1 Yaw Spring 2 to each wing on Bottom, securing the skinny end to Bottom using an M3 bolt from the bottom of the wing into the threaded insert. The bolt should be moderately tight, but still allowing for free rotation of the Yaw Spring 2 parts. Another M3 bolt of the same length should be installed in the middle hole of Yaw Spring 2, keeping the bolt head slightly below the bottom edge of the wing. A third M3 bolt, shorter this time, should be installed in the wide end of Yaw Spring 2 with a short extension spring. The spring should be connected to both Yaw Spring 2 levers and should return Top to center when it is rotated. If the spring is not strong enough, it can be replaced later, once the handle is mounted and spring strength can be accurately tested.

- Now, slide the Bottom part down into hinge_ver_D_-_606_bearings v3 until the perpendicular hole in Bottom lines up with the two bearings in the hinge. Hold it in place using axis_for_ver_D, sliding it flat side first from the side of the hinge with a longer protruding arm. It should stop almost flush with the bearing, but still protruding slightly.

- Slide hinge_cam_slider_for_ver_C v3 into the rectangular slot in the side of hinge_ver_D_-_606_bearings, matching up the long side with the longer hook arm and the rounded section against the V of the Bottom.

- Affix 1 extension spring to either side of hinge_ver_D_-_606_bearings, hooking onto the protruding arms and the hinge_cam_slider_for_ver_C.

- Use isopropyl alcohol to clean the bottoms of both magnet brackets previously prepared.

- Ensuring that the handle mount (Bottom and Top) is in the centered position (the 2 new extension springs are as compressed as possible), use 5 minute epoxy (also recommended: gloves) to glue 1 magnet bracket onto the end of axis_for_ver_D on the side of the hinge assembly that has a gap between the spring and the body. Ensure the bracket is as centered as possible, not stuck to anything beyond the axis shaft (the inner race of the bearing is also acceptable), and is parallel with the bottom of hinge_ver_D_-_606_bearings. Hold it in place until the epoxy sets.

- Clean the end of a short section of the yaw axis shaft protruding from the bottom of the handle mount assembly using isopropyl alcohol.

- Use 5 minute epoxy to glue the other magnet bracket to the end of the yaw axis shaft, ensuring Top is as centered rotationally as possible and that the magnet bracket is rotated such that the open sides of the U face the long face of the bottom of Bottom. Also ensure no epoxy sticks to the printed parts and impedes the rotation of the magnet bracket to +/- ~40 degrees.

- Once both magnet brackets are installed and can rotate freely (and the epoxy has cured), select 1 hall effect sensor (previously prepared), bend the sensor body 90 degrees from the leads/wires, and glue to the side of the hinge_ver_D_-_606_bearings with the sensor body centered between the two magnets in the magnet bracket and on the center of rotation as best as possible using hot glue. Bend the wires such that they follow the top edge of the side profile of hinge_ver_D_-_606_bearings until about 15mm from the front edge (the end with the cavity with the magnets on the bottom) and bend them downwards. Use hot glue to hold the wires in position. Ensure the bearing can still move freely.

- Bend the leads/wires of the third hall effect sensor such that the sensor body is 90 degrees from the leads, and about 10mm away, the wires bend down and flatten out in the same direction as the sensor. Using hot glue, glue the wires to the bottom of Bottom, keeping the sensor body centered in the magnet bracket and over the center of rotation as best as possible.

- Set aside the hinge/handle mount assembly

- Prepare a 3 pin dupont-style (or other style) connector with a black (~3 inch (~75mm)), red(~3 inch (~75mm)), and colored (~1 inch (~25mm)) wires. This is for the external throttle input, so it this step is Optional. Any pinout works, but I recommended having the signal in the middle, then polarity is almost irrelevant (switching the VCC and GND pins simply inverts the input). Ensure the loose end of the colored wire is also stripped. Additionally, prepare the 3 position switch with a ~2 inch (~50mm) colored wire on the middle pin. If using a double pole switch, I recommended connecting the two independent sets of pins in the middle.

- Use the 2 M2*4mm bolts to hold the 3 position switch in its mounting hole. Then slide the wires of the 3 pin connector through the small slot above the switch and bend the colored wire down to the side of the switch that has the E label on the outside and solder in place. Trim the colored wire coming from the internal potentiometer to reach the switch, then strip and solder to the other side of the switch, there should be an I label on the outside on that side of the switch.

- Fit 2 M4 Bearing Spacers in the 2 606 bearings in Mount Base. Fit an M4 nut in the slot near either end of the hinge_ver_D_-_606_bearings, using an M4 bolt to align it properly and holding it in place with a block of hot glue around it, ensuring the hot glue does not interfere with anything else.

- Now, mount the hinge/handle mount assembly in Mount Base using 2 M4 Bolts. A button-head M4 bolt must be used on the interior bearing. The exterior bearing can use any style of M4 Bolt, as long as it is the correct length.

- Pull all wires from the mounting assembly through the side next to the external throttle input.

- Separate all the blacks wires and all the red wires and trim each to a common length, keeping the two groups at different lengths (if possible) so that they cannot short against each other. Strip all these wires and solder all black wires together and all red wires together.

- Prepare the ADC with pin headers. Then, fit the ADC in the base assembly below the external throttle input. Connect the center wire from the switch to one analog input of the ADC. Connect the 3 colored wires from the hall effect sensors to the other 3 analog inputs of the ADC. Connect a black wire long enough to reach from the common ground point to the GND pin of the ADC. Repeat with a red wire from the common 5V point to the VCC pin of the ADC. Trim and solder a 4.7K Ohm resistor to the SDA and SCL pins of the ADC. Connect the other end of the resistors to 5V. Then solder a ~1 inch (~25mm) colored wire to SDA and SCL. Write down which wire goes to which pin.

- Fit the Arduino Pro Micro (and pin headers) into the electronics section, ensuring the micro usb port is pointing towards the cutout on the side of the potentiometer. Use a small glob of hot glue to secure the Arduino board in place.

- Connect the SDA pin from the ADC to pin 2 of the Arduino Pro Micro. Connect the SCL pin of the ADC to pin 3 of the Arduino Pro Micro. Then use a short length of red wire to connect the VCC pin of the Arduino to the common 5V point and a short length of black wire to connect a GND pin from the Arduino to the common ground point.

- Test that the ADC is working properly using the joystick test code and all optional settings disabled. As each axis is moved the values should increase or decrease. Ensure that all 4 axes are working properly and that nothing has come loose or collided. (Remember that the potentiometer is on a switch, so it should be set to the I side before the internal one works.

- Test the fit of base_cover, moving wires and trimming base_cover where needed. Test all 4 axes again to ensure everything still works

- Once everything is verified to be working as intended, the handle can be mounted. Remove the single M3 bolt in the lower section of the handle assembly. Fit the handle on the Top piece, the handle should be tilted towards the electronics area. Once fit properly, the M3 bolt removes from the handle should be reinserted and should slide through the hole in the side of Top as well. Drill out the hole if necessary.

- Bend the wires from the handle in a wide loop such that they end pointing towards the rectangular cutout in base_cover. Ensure the handle maintains its full range of motion (including yaw) with the wires pinned at the end here. Also adjust the length needed.

- Once a satisfactory position and length for the wires has been found, trim the wires to length and separate all the wires at the end ~1 inch (~25mm). Remove base_cover.

- Prepare an 8 pin dupont-style connector (or other 8 pin connector) by crimping long and short pins to all 8 wires from the joystick. Ensure there is at least 1 of both types of pin. Fit all 8 wires into a connector part, writing down which pin on the connector is which communications or power wire. (If building multiple joysticks, I recommended using the same pinout for both on this connector)

- Create the other end of the 8 pin connector that was just made for the handle. Use wires long enough to reach from the Arduino Pro Micro, out the rectangular cutout in base_cover, and to the desired connecting position for the handle. Also include an extra ~5mm just in case. Crimp the appropriate pins to each wire and fit in the connector housing. As the wires are soldered to the Arduino Pro Micro, write down which Arduino pin is connected to which function based on where that wire is positioned in the connector.

- Using the test code once again, ensure that all the axes still work as expected and that every button works individually.

- Once everything is verified to be working, reinstall base_cover and hold in place using a few ~1 inch (~25mm) lines of hot glue along the seem. Test everything is still working. Use isopropyl alcohol to peel the hot glue off if needed.

- Once everything is still working with the base_cover installed, trace along the entirety of the seem between the cover and the base with hot glue.

- The build is now finished. Calibrate your joystick, then you can use it!

# Throttle Build Instructions
- If the base and cover were printed in 2 pieces, cut the 3 3mm rods into 7 80mm lengths. Bevel both ends of all 7 rods.

- Clean the 7 rods with isopropyl alcohol. Prep the base and cover to be glued together by placing a piece of masking tape on one side of the joint that overlaps halfway with the joint.

- If using rubber gloves, put them on now.

- Use 5 minute epoxy to glue 5 of the rods into the base by dripping some epoxy into each rod hole on both sides, smearing some epoxy along the plastic V, inserting the rods into the holes on one side, then pressing the other side onto the rods until the two plastic surfaces meet, then use the masking tape to cover the joint and prevent epoxy from leaking out.

- Use 5 minute epoxy to glue the remaining two rods into the cover by dripping some epoxy down both holes on both sides of the cover, then smearing epoxy along the mating surface on one side. Slide the rods into the holes on one half of the cover, then slide the other half of the cover over the rods. Once fully pressed together, use the masking tape to reduce epoxy leakage.

- Use 5 minute epoxy to glue 1 50 tooth GT2 pulley to the middle of the Idler Axle (ensure it is as perpendicular to the axle as possible). Then glue the 20 tooth MXL pulley (or substitute) to one end of the Drive Axle.

- Use the 8 small zip ties to affix the 4 linear bearings to the bottom of Mount, 2 zip ties per bearing, looping through the holes and guides. I recommended Keeping the heads of the zip ties towards the middle to avoid clearance issues.

- Use 5 minute epoxy to glue Mount Side to Mount, lining up the grooved teeth. Test fit before applying epoxy, removing material from the joint where necessary. Try not to glue the zip ties into place.

- Prepare the 4 Adjustable Bearing Pillow Blocks by fitting 1 606 bearing into each (if loose, use epoxy to affix after cleaning the grease off with isopropyl alcohol).

- Prepare the Adjustable Pot Mount by fitting the potentiometer and fixing it in place using the included washer and nut.

- Use 5 minute epoxy to glue in 6 neodymium magnets into the 6 holes along the perimeter of Base. Also glue in 6 magnets into Cover, ensuring that all magnets are attracting each other.

- Once the epoxy has set on the Drive Axle, fit one Adjustable Bearing Pillow Block on the long end of the Drive Axle, then a washer (can be printed), then use 5 minute epoxy to glue on the other 50 tooth GT2 pulley, trapping the bearing and pillow block in the middle.

- Once all the epoxy has cured, use the soldering iron and the tip for the M3 inserts to press 4 inserts into the bottom of the Base, 2 inserts into the top side of the holes on Mount Side, and 2 inserts into the bottom of all 5 (Adjustable Bearing Pillow Block * 4 and Adjustable Pot Mount * 1) adjustable mounts.

- Using short M3 bolts and washers, affix all 5 adjustable mounts on Base. The potentiometer mount is the only mount that should stretch across two slots.

- Clean the 2 8mm*330mm steel rods using isopropyl alcohol.

- Apply a few drops of grease inside each linear bearing.

- Fit the 2 8mm*330mm steel rods in the two holes in the base. As they are slide through, slide the linear bearings on the bottom of Mount onto the steel rods. Slide in as far as possible (they should go into holes in the other end of the large slots). The Mount carriage should slide freely from end to end. Hold the rods in place by filling the holes they were slide through with hot glue up to the surface of the printed part.

- Measure out ~18 inches (~450mm) of 3 wires (ideally joined in a ribbon cable). Solder one end to the three pins on the potentiometer. Tack a section of the wire to the base near the middle so that the wire can still bend freely beyond that point and can reach the groove in Mount Side between the 2 M3 inserts. Glue the wire in that groove, leaving enough past it so that it can bend around and reach the external throttle connector when a joystick is mounted to the carriage.

- Split the 3 wires apart at the loose end and join in a connector, matching the connector and pinout used on the external throttle connector on the joystick. 

- Next, fit 2 M3*35 bolts through Belt Pin Spacer, then screw both bolts into the two m3 inserts in Mount Side, keeping the potentiometer wire below the spacer.

- Then, measure out the appropriate length of GT2 belt and cut to length, ensuring enough extra is left for it to wrap around the 2 bolts as well as the 2 50 tooth pulleys.

- Loop the GT2 belt under and around both 50 tooth pulleys, then back towards to bolts on mount side.

- Fit a X-Belt-Holder-Thin-GT2 over either end of the belt, then loop one side over the closer bolt, fold back on itself around the bolt such that the teeth of the belt interlocks, then slide the belt holder over the overlap to hold it in place. Repeat this for the other end of the belt around the other bolt, this time pulling the belt moderately tight.

- Loosen the bolts on the bottom of the idler pulley assembly, then pull both bearing blocks back, tightening the belt. Then tighten the bolts on the bottom again to lock this position in.

- Slide the carriage to one extreme.

- Press the 40 tooth MXL pulley onto the potentiometer shaft and turn potentiometer to the same extreme end as the carriage.

- Loosen the 2 bolts holding the potentiometer mount in position and install the closed loop MXL belt over the 20 tooth and 40 tooth pulleys. Then tighten the belt by sliding the potentiometer mount and tighten on bolts on the bottom of the potentiometer mount when a satisfactory tension has been reached.

- Ensure that the carriage moves with little resistance in its full range of motion and that the potentiometer is spun for the whole range of motion.

- Install a joystick using 4 M3 bolts through the 4 mounting holes in Mount. The bolts are fed up from the bottom, on either side of 2 of the linear bearings. Then plug in the connector from the mounting carriage into the external input, and slide the switch to the external side.

- Calibrate the throttle input as desired then the throttle is completed and ready for use.

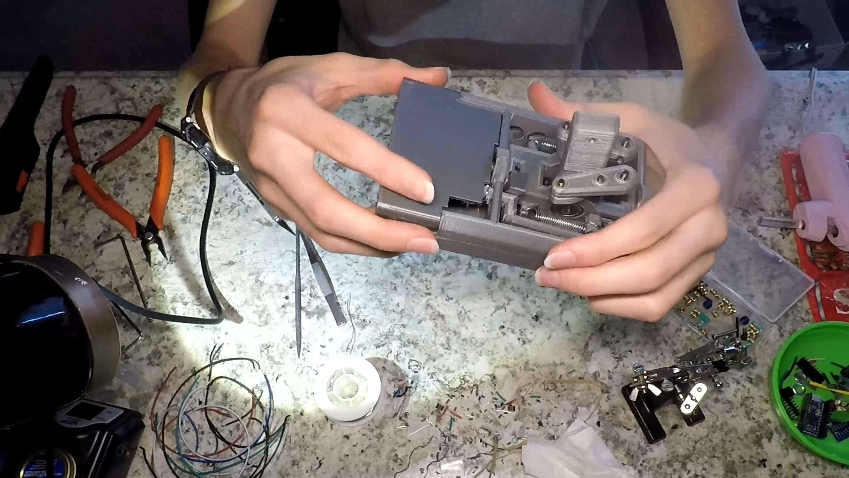
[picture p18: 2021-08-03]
Images/Pictures From Build Guide Video/Untitled_2.1.21.jpg

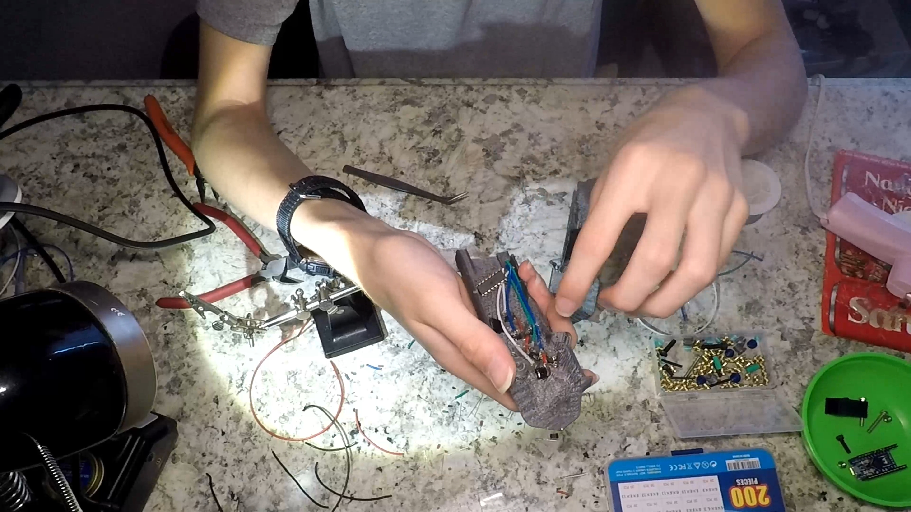
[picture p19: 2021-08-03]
Images/Pictures From Build Guide Video/Untitled_2.1.15.jpg

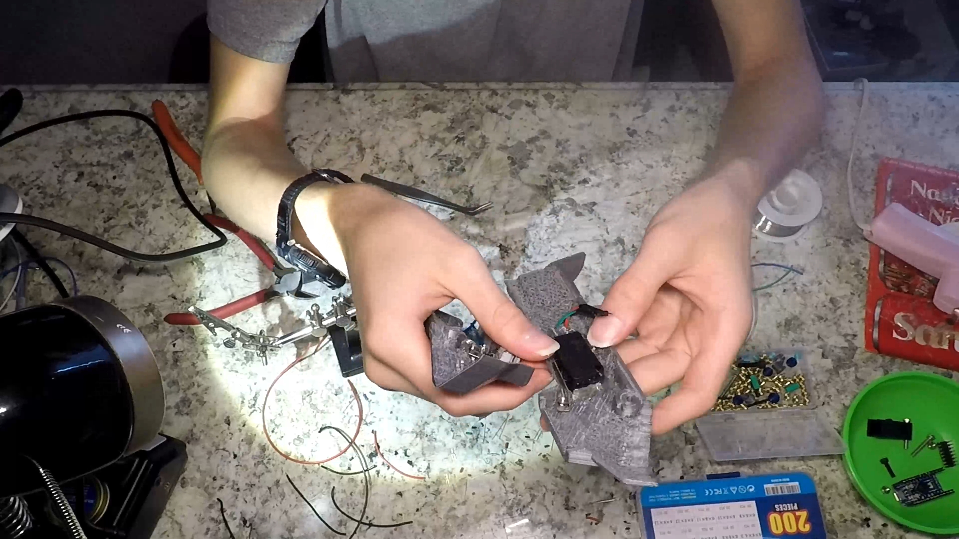
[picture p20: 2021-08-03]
Images/Pictures From Build Guide Video/Untitled_2.1.13.jpg

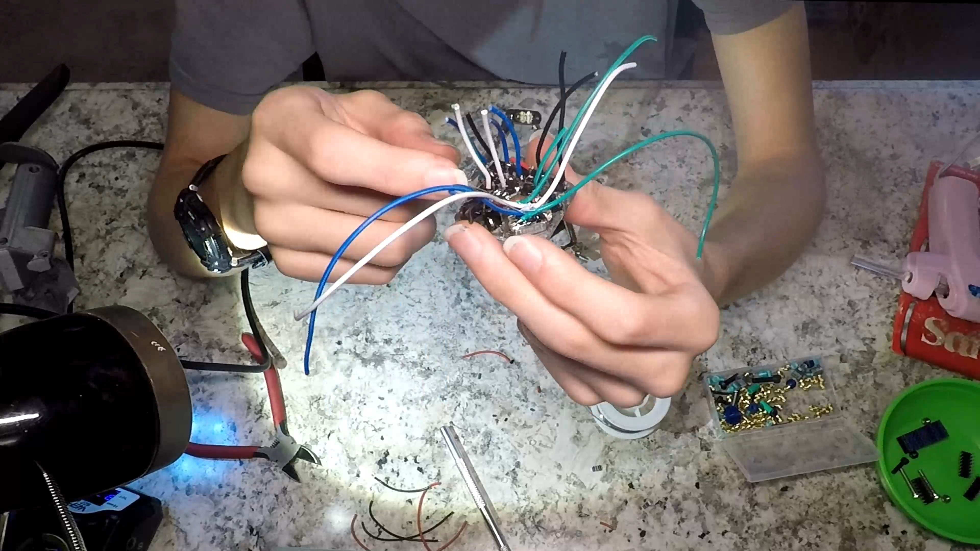
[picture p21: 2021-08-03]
Images/Pictures From Build Guide Video/Untitled_2.1.5.jpg

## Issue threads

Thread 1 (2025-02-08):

i want to build this too

thekillerlvl900, 2025-02-08:
hey man i commented on your youtube video but i really would like to buy this too so if i could have some help it would be greatly appreciate

thekillerlvl900, 2025-02-09:
by chance if you have this video without the 5x speed that would be greatly appreciate https://www.youtube.com/watch?v=Amg51pNDD08&ab_channel=JordanKooyman

jordankooyman, 2025-02-09:
I am currently working on rendering and uploading such a video. It is the raw source footage stitched together, with a few bits cut out due to file read errors. I hope to have the videos ready in about 12 hours, depending on how long YouTube takes to process. It is approximately 12hrs long, split into 3 videos due to technical difficulties.
________________________________
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

thekillerlvl900, 2025-02-09:
oh wow thank you take your time man im in no hurry and thank you so much

jordankooyman, 2025-02-09:
Please see the following playlist, it contains all the videos from this project, including the new raw build videos.
[Joystick Project Videos](https://www.youtube.com/playlist?list=PLXZElHltdDC3ivyHnzJAsZEHW-QBpOuhP)

Closed 2025-02-09.

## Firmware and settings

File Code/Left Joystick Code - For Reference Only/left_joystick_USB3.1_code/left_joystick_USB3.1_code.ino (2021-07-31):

//Written By: Jordan Kooyman
//		7/2021

//Button Number Mapping:
//Numbers adjusted for missing hat inputs

//Face: (up,down,left,right,click)
//           (0,2,1,3,19)
//       3                 7
//    2      0         6      8
//       1        4-5        9
//           4-5       10
//                11


//Grip (Side View):
//           17
//         14  16
//
//                    18 (Trigger)
//
//         13      15
//
//
//         12

//          Min/Max Values, Center Deadzone Range, and Inversion Configuration
#define Pitch_max_value 12800  //Set to the max value of Pitch Axis
#define Pitch_min_value 8500  //Set to the min value of Pitch Axis
#define deadzone_lower_Pitch 9750 //10150  //Set these to the lower and upper limits of Pitch wiggle on joystick before springs kick in
#define deadzone_upper_Pitch 10400 //10300  //Set to the same as the lower to disable
#define invert_Pitch 1  //Change the sign on the 1 to invert the Pitch axis

#define Roll_max_value 17500  //Set to the max value of Roll Axis
#define Roll_min_value 8500  //Set to the min value of Roll Axis
#define deadzone_lower_Roll 12000 //12720  //Set these to the lower and upper limits of Roll wiggle on joystick before springs kick in
#define deadzone_upper_Roll 13000 //12800  //Set to the same as the lower to disable
#define invert_Roll -1  //Change the sign on the 1 to invert the Roll axis

#define Yaw_max_value 14900  //Set to the max value of Yaw Axis
#define Yaw_min_value 7700  //Set to the min value of Yaw Axis
#define deadzone_lower_Yaw 11000-250 //11230  //Set these to the lower and upper limits of Yaw wiggle on joystick before springs kick in
#define deadzone_upper_Yaw 11400-250 //11440  //Set to the same as the lower to disable
#define invert_Yaw 1  //Change the sign on the 1 to invert the Yaw axis

#define Throttle_max_value 24500  //Set to the max value of Throttle Axis
#define Throttle_min_value 0  //Set to the min value of Throttle Axis
#define deadzone_lower_Throttle 11700 //12000  //Set these to the lower and upper limits of Throttle wiggle on joystick before springs kick in
#define deadzone_upper_Throttle 12800 //12000  //Set to the same as the lower to disable
#define invert_Throttle 1  //Change the sign on the 1 to invert the Throttle axis

//          The Shift Register pins the HAT switch is connected to
#define hat_up 0
#define hat_down 2
#define hat_left 1
#define hat_right 3

//          Colors for output wires on Right Joystick Handle V1
#define CLOCK_PIN2 7  //Green - Black
#define SERIAL_IN_PIN2 6 //Blue - Black
#define LOAD_DATA_PIN2 18  //Red - Black
#define CLOCK_PIN 16  //Green - Red
#define SERIAL_IN_PIN 4 //Blue - Red
#define LOAD_DATA_PIN 21  //White - Red

//#define SCL_PIN 3
//#define SDA_PIN 2

//          End of Configuration

#define deadzone_range_Pitch ((deadzone_lower_Pitch - deadzone_upper_Pitch) / 2)  //Do not touch - calculate half of the range of the deadzone
#define Pitch_range ((Pitch_max_value - Pitch_min_value) / 2)  //Do not touch - calculate half the range of possible input values - used to offset this axis around 0 to allow for inverting
#define offset_Pitch (Pitch_range - deadzone_range_Pitch)  //Do not touch - Calculate the difference between the deadzone middle and value range middle - used to align deadzone with data middle
#define Pitch_offset (Pitch_range + Pitch_min_value + offset_Pitch)  //Do not touch - calculate the offset from zero the center of the range of possible values is
#define max_Pitch (Pitch_range  - deadzone_range_Pitch)  //Do not touch - calculate the software max value based on previous configuration
#define min_Pitch (-1 * max_Pitch)  //Do not touch - calculate the software min value based on previous configuration

#define deadzone_range_Roll ((deadzone_lower_Roll - deadzone_upper_Roll) / 2)  //Do not touch - calculate half of the range of the deadzone
#define Roll_range ((Roll_max_value - Roll_min_value) / 2)  //Do not touch - calculate half the range of possible input values - used to offset this axis around 0 to allow for inverting 
#define offset_Roll (Roll_range - deadzone_range_Roll)  //Do not touch - Calculate the difference between the deadzone middle and value range middle - used to align deadzone with data middle
#define Roll_offset (Roll_range + Roll_min_value + offset_Roll)  //Do not touch - calculate the offset from zero the center of the range of possible values is
#define max_Roll (Roll_range + deadzone_range_Roll)  //Do not touch - calculate the software max value based on previous configuration
#define min_Roll (-1 * max_Roll)  //Do not touch - calculate the software min value based on previous configuration

#define deadzone_range_Yaw ((deadzone_lower_Yaw - deadzone_upper_Yaw) / 2)  //Do not touch - calculate half of the range of the deadzone
#define Yaw_range ((Yaw_max_value - Yaw_min_value) / 2)  //Do not touch - calculate half the range of possible input values - used to offset this axis around 0 to allow for inverting
#define offset_Yaw (Yaw_range - deadzone_range_Yaw)  //Do not touch - Calculate the difference between the deadzone middle and value range middle - used to align deadzone with data middle
#define Yaw_offset (Yaw_range + Yaw_min_value + offset_Yaw)  //Do not touch - calculate the offset from zero the center of the range of possible values is
#define max_Yaw (Yaw_range - deadzone_range_Yaw)  //Do not touch - calculate the software max value based on previous configuration
#define min_Yaw (-1 * max_Yaw)  //Do not touch - calculate the software min value based on previous configuration

#define deadzone_range_Throttle ((deadzone_lower_Throttle - deadzone_upper_Throttle) / 2)  //Do not touch - calculate half of the range of the deadzone
#define Throttle_range ((Throttle_max_value - Throttle_min_value) / 2)  //Do not touch - calculate half the range of possible input values - used to offset this axis around 0 to allow for inverting
#define offset_Throttle (Throttle_range - deadzone_range_Throttle)  //Do not touch - Calculate the difference between the deadzone middle and value range middle - used to align deadzone with data middle
#define Throttle_offset (Throttle_range + Throttle_min_value + offset_Throttle)  //Do not touch - calculate the offset from zero the center of the range of possible values is
#define max_Throttle (Throttle_range - deadzone_range_Throttle)  //Do not touch - calculate the software max value based on previous configuration
#define min_Throttle (-1 * max_Throttle)  //Do not touch - calculate the software min value based on previous configuration




#include <Joystick.h>
#include <Adafruit_ADS1X15.h>

Adafruit_ADS1115 ads;

Joystick_ Joystick(0x05,JOYSTICK_TYPE_JOYSTICK, //hid report ID, hid device type
  20, 1,                  // Button Count, Hat Switch Count
  true, true, true,     // X , Y, and Z Axis
  false, false, false,   // No Rx, Ry, or Rz
  false, true,            // No rudder, yes throttle
  false, false, false);  // No accelerator, brake, or steering

int j;
int l;
int k;
int value;
int out_enable = 0;
int lastButtonState[5] = {2,2,2,2,2};  //Up, Right, Down, Left, Cleared --  Hat Button State
int lastClickState[20] = {2,2,2,2,2,2,2,2,2,2,2,2,2,2,2,2,2,2,2,2};  //The 20 non-HAT buttons



void setup() {
  pinMode(LOAD_DATA_PIN, OUTPUT);
  pinMode(CLOCK_PIN, OUTPUT);
  pinMode(SERIAL_IN_PIN, INPUT);
  pinMode(LOAD_DATA_PIN2, OUTPUT);
  pinMode(CLOCK_PIN2, OUTPUT);
  pinMode(SERIAL_IN_PIN2, INPUT);

  ads.begin();
//  ads.setGain(GAIN_TWOTHIRDS);  // 2/3x gain +/- 6.144V  1 bit = 3mV (default)
//  ads.setGain(GAIN_ONE);     // 1x gain   +/- 4.096V  1 bit = 2mV
//  ads.setGain(GAIN_TWO);     // 2x gain   +/- 2.048V  1 bit = 1mV
//  ads.setGain(GAIN_FOUR);    // 4x gain   +/- 1.024V  1 bit = 0.5mV
//  ads.setGain(GAIN_EIGHT);   // 8x gain   +/- 0.512V  1 bit = 0.25mV
//  ads.setGain(GAIN_SIXTEEN); // 16x gain  +/- 0.256V  1 bit = 0.125mV

// Initialize Joystick Library
  Joystick.begin(false); //false = dont send automatically. We will sendState() at the end of the loop
  Joystick.setYAxisRange(min_Pitch, max_Pitch); //Pitch 8000-13000
  Joystick.setXAxisRange(min_Roll, max_Roll); //Roll 7900-15300
  Joystick.setZAxisRange(min_Yaw, max_Yaw); //Yaw  10400-14200
  Joystick.setThrottleRange(min_Throttle, max_Throttle);
}

void loop() {
  value = -1;
  //Front Panel Shift Registers (2 daisy-chained)
  digitalWrite(LOAD_DATA_PIN, 0);  // Allow data to load on clock pulse
  digitalWrite(CLOCK_PIN, 0);  // load in data
  digitalWrite(CLOCK_PIN, 1);
  digitalWrite(LOAD_DATA_PIN, 1);  // Stop data updates on clock pulse

  //Handle Shift Register
  digitalWrite(LOAD_DATA_PIN2, 0);  // Allow data to load on clock pulse
  digitalWrite(CLOCK_PIN2, 0);  // load in data
  digitalWrite(CLOCK_PIN2, 1);
  digitalWrite(LOAD_DATA_PIN2, 1);  // Stop data updates on clock pulse

for(k = 12; k < 20; k++) { // Handle Shift Register with offset to allow for the first two to take the first 13 inputs (3 go to HAT Switch)
  value = digitalRead(SERIAL_IN_PIN2);
    if (lastClickState[k] != value) {  //  Button in new state
      Joystick.setButton(k, value); //pin HIGH means button PRESSED  -- update the joystick button press state
      lastClickState[k] = value;  //  Update reference array to reflect new state
      }
    if (k == 13) { out_enable = value; }

  digitalWrite(CLOCK_PIN2, LOW);  //  Toggle Clock Pin for another bit of data
  digitalWrite(CLOCK_PIN2, HIGH);
}

for(j = 0; j < 16; j++) {  //  Front Panel Shift Registers
  value = digitalRead(SERIAL_IN_PIN);
      if (j == hat_up) {  // if hat switch pin (on shift register, not arduino)
        if (value != lastButtonState[0]) {  // if the value has changed since the last check
          if (value == 1) {Joystick.setHatSwitch(0, 0);}  //  if the value is not release (because there is seperate code to release later on)
          lastButtonState[0] = value;  //  update reference array with new position state
          lastButtonState[4] = 0;  //  Allow the releasing code to run when all other HAT switch inputs are released
        }
      }
      else if (j == hat_down) { // if hat switch pin (on shift register, not arduino)
        if (value != lastButtonState[2]) {  // if the value has changed since the last check
          if (value == 1) {Joystick.setHatSwitch(0, 180);}  //  if the value is not release (because there is seperate code to release later on)
          lastButtonState[2] = value;  //  update reference array with new position state
          lastButtonState[4] = 0;  //  Allow the releasing code to run when all other HAT switch inputs are released
        }
      }
      else if (j == hat_left) { // if hat switch pin (on shift register, not arduino)
        if (value != lastButtonState[3]) {  // if the value has changed since the last check
          if (value == 1) {Joystick.setHatSwitch(0, 270);}  //  if the value is not release (because there is seperate code to release later on)
          lastButtonState[3] = value;  //  update reference array with new position state
          lastButtonState[4] = 0;  //  Allow the releasing code to run when all other HAT switch inputs are released
        }
      }
      else if (j == hat_right) {
        if (value != lastButtonState[1]) {  // if the value has changed since the last check
          if (value == 1) {Joystick.setHatSwitch(0, 90);}  //  if the value is not release (because there is seperate code to release later on)
          lastButtonState[1] = value;  //  update reference array with new position state
          lastButtonState[4] = 0;  //  Allow the releasing code to run when all other HAT switch inputs are released
        }
      }
      else {  // If not a hat switch pin, it must be a button pin
        l = j;
        if (j > hat_right) {l -= 4;}  //Missing hat switch pins numbering adjustment
        if (lastClickState[l] != value) {  //  if the state of the button has changed
          Joystick.setButton(l, value); //pin HIGH means button PRESSED  -- update the joystick button press state
          lastClickState[l] = value;  //  update reference array with new button state
        }
      }
      if ((lastButtonState[0] == 0)  // Resetting HAT switch if no other state is set and it has not already done so
        && (lastButtonState[1] == 0)
        && (lastButtonState[2] == 0)
        && (lastButtonState[3] == 0)
        && (lastButtonState[4] == 0)){
          Joystick.setHatSwitch(0, -1);
          lastButtonState[4] = 1;  //  Prevent this code from running again until the HAT switch is clicked first
      }

  
  digitalWrite(CLOCK_PIN, LOW);  //  Toggle Clock Pin for another bit of data
  digitalWrite(CLOCK_PIN, HIGH);
}

//Use the 16-bit ADC (ADS1115) connected via I2C to read the 4 encoders (3 hall sensors and 1 potentiometer) instead of using the built in 12-bit ADC
int16_t adc0; // 16 bits ADC read of input A0
adc0 = ads.readADC_SingleEnded(0);  //Z Yaw  10400-14200
int16_t adc1; // 16 bits ADC read of input A1
adc1 = ads.readADC_SingleEnded(1);  //Y Pitch 8000-13000
int16_t adc2; // 16 bits ADC read of input A2
adc2 = ads.readADC_SingleEnded(2);  // Throttle  0-24850
int16_t adc3; // 16 bits ADC read of input A3
adc3 = ads.readADC_SingleEnded(3);  //X Roll 7900-15300


//Deadzone addition

if (adc0 < deadzone_lower_Yaw) {
  adc0 += deadzone_range_Yaw + 1000;
}
else if (adc0 > deadzone_upper_Yaw) {
  adc0 -= deadzone_range_Yaw + 300;
}
else {
  adc0 = ((0 + Yaw_offset - offset_Yaw));//deadzone_lower_Yaw + deadzone_range_Yaw + Yaw_trim;
}   
adc0 += offset_Yaw;

if (adc1 < deadzone_lower_Pitch) {
  adc1 += deadzone_range_Pitch + 1200;
}
else if (adc1 > deadzone_upper_Pitch) {
  adc1 -= deadzone_range_Pitch + 50;
}
else {
  adc1 = ((0 + Pitch_offset - offset_Pitch));//deadzone_range_Pitch + deadzone_lower_Pitch + Pitch_trim;
} 
adc1 += offset_Pitch;  

if (adc2 < deadzone_lower_Throttle) {
  adc2 += deadzone_range_Throttle + 1100;
}
else if (adc2 > deadzone_upper_Throttle) {
  adc2 -= deadzone_range_Throttle + 1100;
}
else {
  adc2 = ((0 + Throttle_offset - offset_Throttle));//deadzone_lower_Throttle + deadzone_range_Throttle + Throttle_trim;
}  
adc2 += offset_Throttle; 

if (adc3 < deadzone_lower_Roll) {
  adc3 += deadzone_range_Roll + 1500;
}
else if (adc3 > deadzone_upper_Roll) {
  adc3 -= deadzone_range_Roll + 500;
}
else {
  adc3 = ((0 + Roll_offset - offset_Roll));//deadzone_lower_Roll + deadzone_range_Roll + Roll_trim;
}   
adc3 += offset_Roll;

adc3 = ((adc3 - Roll_offset) * invert_Roll);
adc1 = ((adc1 - Pitch_offset) * invert_Pitch);
adc0 = ((adc0 - Yaw_offset) * invert_Yaw);
adc2 = ((adc2 - Throttle_offset) * invert_Throttle);

if (adc0 > 0) {adc0 = adc0 / 1.15;}//Yaw
if (adc1 > 0) {adc1 = adc1 / 1.0;}//Pitch
if (adc3 > 0) {adc3 = adc3 / 1.4;}//Roll
if (adc2 > 0) {adc2 = adc2 / 1.005;}//Throttle
  
//Prevent the values from exceding the defined limits
if (adc0 > max_Yaw - 1) {adc0 = max_Yaw - 1;}
if (adc0 < min_Yaw + 1) {adc0 = min_Yaw + 1;}
if (adc1 > max_Pitch - 1) {adc1 = max_Pitch - 1;}
if (adc1 < min_Pitch + 1) {adc1 = min_Pitch + 1;}
if (adc2 > max_Throttle - 1) {adc2 = max_Throttle - 1;}
if (adc2 < min_Throttle + 1) {adc2 = min_Throttle + 1;}
if (adc3 > max_Roll - 1) {adc3 = max_Roll - 1;}
if (adc3 < min_Roll + 1) {adc3 = min_Roll + 1;}

//set analog axes
if (out_enable == 1) { // If Button 12 (lowest grip button) is held, output the joystick data, otherwise set it to 0 as the output
  Joystick.setXAxis(adc3);
  Joystick.setYAxis(adc1);
  Joystick.setZAxis(adc0);
}
else {
  Joystick.setXAxis(0);
  Joystick.setYAxis(0);
  Joystick.setZAxis(0);
}
Joystick.setThrottle(adc2);
  
Joystick.sendState();
delay(10);
}

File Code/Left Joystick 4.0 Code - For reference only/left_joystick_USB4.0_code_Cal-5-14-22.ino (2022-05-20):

//Button Number Mapping:
//Numbers adjusted for missing hat inputs

//Face: (up,down,left,right,click)
//           (0,2,1,3,19)
//       3                 7
//    2      0         6      8
//       1        4-5        9
//           4-5       10
//                11


//Grip (Side View):
//           17
//         14  16
//
//                    18 (Trigger)
//
//         13      15
//
//
//         12

#define Deadzone_max_propotion 1 // 1 out of 'this number' is the largest portion the deadzone can be of the total input range - set to 1 to ignore
#define Output_delay 100 // How long to pause between read/update cycles
//#define Serial_Mode 1 // Comment out to use Joystick library, otherwise outputs data to Serial monitor at 9600 baud: 1 - Raw Data, 2 - Processed Data

//          Min/Max Values, Deadzone Min/Max Values, and Inversion Configuration
#define Pitch_max_value 12800    // Set to the max value of Pitch Axis
#define Pitch_min_value 8500    // Set to the min value of Pitch Axis
#define Pitch_max_deadzone 10350 // Set to the max value of the desired deadzone
#define Pitch_min_deadzone 9500 // Set to the min value of the desired deadzone
#define Pitch_ADC 1              // Set to the adc pin number this axis is connected to (between 0 and 3 inclusive)
#define invert_Pitch_axis 1     // Change the sign on the 1 to invert the Pitch axis

#define Roll_max_value 16000    // Set to the max value of Roll Axis
#define Roll_min_value 8300    // Set to the min value of Roll Axis
#define Roll_max_deadzone 14100 // Set to the max value of the desired deadzone
#define Roll_min_deadzone 12600 // Set to the min value of the desired deadzone
#define Roll_ADC 3              // Set to the adc pin number this axis is connected to (between 0 and 3 inclusive)
#define invert_Roll_axis -1     // Change the sign on the 1 to invert the Roll axis

#define Yaw_max_value 15000    // Set to the max value of Yaw Axis
#define Yaw_min_value 8000    // Set to the min value of Yaw Axis
#define Yaw_max_deadzone 11800 // Set to the max value of the desired deadzone
#define Yaw_min_deadzone 10600 // Set to the min value of the desired deadzone
#define Yaw_ADC 0              // Set to the adc pin number this axis is connected to (between 0 and 3 inclusive)
#define invert_Yaw_axis 1     // Change the sign on the 1 to invert the Yaw axis

#define Throttle_max_value 24300    // Set to the max value of Throttle Axis
#define Throttle_min_value 300    // Set to the min value of Throttle Axis
#define Throttle_max_deadzone 12800 // Set to the max value of the desired deadzone
#define Throttle_min_deadzone 11700 // Set to the min value of the desired deadzone
#define Throttle_ADC 2              // Set to the adc pin number this axis is connected to (between 0 and 3 inclusive)
#define invert_Throttle_axis 1     // Change the sign on the 1 to invert the Throttle axis

//          The Shift Register pins the HAT switch is connected to
#define hat_up 0
#define hat_down 2
#define hat_left 1
#define hat_right 3

//          Colors for output wires on Right Joystick Handle V1
#define CLOCK_PIN2 7  //Green - Black
#define SERIAL_IN_PIN2 6 //Blue - Black
#define LOAD_DATA_PIN2 18  //Red - Black
#define CLOCK_PIN 16  //Green - Red
#define SERIAL_IN_PIN 4 //Blue - Red
#define LOAD_DATA_PIN 21  //White - Red

//#define SCL_PIN 3
//#define SDA_PIN 2

//          End of Configuration


//          Axis value calculations - Do not modify

#if Deadzone_max_propotion < 1 // Ensure some deadzone range checking is performed
#error Deadzone_max_propotion must be at least 1
#endif

// Pitch calculations
#define Pitch_deadzone_Range ((Pitch_max_deadzone - Pitch_min_deadzone) / 2) // Calculate based on input min and max values
#define Pitch_center_location (Pitch_min_deadzone + Pitch_deadzone_Range) // Calculate based on deadzone values

#define Pitch_range_up (Pitch_max_value - Pitch_center_location)
#define Pitch_range_down (Pitch_center_location - Pitch_min_value)

// Use the smaller range-of-motion axis to determine input range
#if Pitch_range_up > Pitch_range_down // Pitch min is limiting axis
#define Pitch_range (Pitch_range_down)
#define Pitch_max_offset_factor (Pitch_range_up / Pitch_range_down) // Used to scale max values to within range (larger / smaller)
#else // Pitch max is limiting axis
#define Pitch_range (Pitch_range_up)
#define Pitch_min_offset_factor (Pitch_range_down / Pitch_range_up) // Used to scale min values to within range (larger / smaller)
#endif

// Pitch deadzone range checking
#if ((Pitch_center_location + Pitch_range) < (Pitch_max_deadzone * Deadzone_max_propotion))
#error Pitch max deadzone is too large.
#endif
#if ((Pitch_center_location - Pitch_range) > (Pitch_min_deadzone / Deadzone_max_propotion))
#error Pitch min deadzone is too small.
#endif
#if (Pitch_max_deadzone <= Pitch_min_deadzone)
#error Pitch deadzone range too small (or negative)
#endif

#define max_Pitch (Pitch_range + 1)  // Maximum possible value to be output
#define min_Pitch (-1 * max_Pitch)  // Minimum possible value to be output



// Roll calculations
#define Roll_deadzone_Range ((Roll_max_deadzone - Roll_min_deadzone) / 2) // Calculate based on input min and max values
#define Roll_center_location (Roll_min_deadzone + Roll_deadzone_Range) // Calculate based on deadzone values

#define Roll_range_up (Roll_max_value - Roll_center_location)
#define Roll_range_down (Roll_center_location - Roll_min_value)

// Use the smaller range-of-motion axis to determine input range
#if Roll_range_up > Roll_range_down // Roll min is limiting axis
#define Roll_range (Roll_range_down)
#define Roll_max_offset_factor (Roll_range_up / Roll_range_down) // Used to scale max values to within range (larger / smaller)
#else // Roll max is limiting axis
#define Roll_range (Roll_range_up)
#define Roll_min_offset_factor (Roll_range_down / Roll_range_up) // Used to scale min values to within range (larger / smaller)
#endif

// Roll deadzone range checking
#if ((Roll_center_location + Roll_range) < (Roll_max_deadzone * Deadzone_max_propotion))
#error Roll max deadzone is too large.
#endif
#if ((Roll_center_location - Roll_range) > (Roll_min_deadzone / Deadzone_max_propotion))
#error Roll min deadzone is too small.
#endif
#if (Roll_max_deadzone <= Roll_min_deadzone)
#error Roll deadzone range too small (or negative)
#endif

#define max_Roll (Roll_range + 1)  // Maximum possible value to be output
#define min_Roll (-1 * max_Roll)  // Minimum possible value to be output



// Yaw calculations
#define Yaw_deadzone_Range ((Yaw_max_deadzone - Yaw_min_deadzone) / 2) // Calculate based on input min and max values
#define Yaw_center_location (Yaw_min_deadzone + Yaw_deadzone_Range) // Calculate based on deadzone values

#define Yaw_range_up (Yaw_max_value - Yaw_center_location)
#define Yaw_range_down (Yaw_center_location - Yaw_min_value)
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

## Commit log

2021-07-30 Initial Code Upload
    The first revision of the sample code and my personal (older version) of the code.
2021-07-30 Add existing file
    [20T 2.75mm MXL Pully.stl, 40T 2.75mm MXL Pully for Pot.stl, 5-way button spacer.stl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]
2021-07-31 Update Documentation and Correct Errors
    [20T 2.75mm MXL Pulley.stl, 20T 2.75mm MXL Pully.stl, 40T 2.75mm MXL Pulley for Pot.stl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]
2021-08-02 Finish Documentation V1
    [axis_for_ver_D v3.stl, hinge_ver_D_-_606_bearings v3.stl]
2022-05-20 Improved Joystick Sample Code
    Many of the joystick axis calculations were rewritten from the ground up to be much more logical, and preprocessor/compiler directives were used to eliminate the need for multiple files, one to test/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
2022-10-29 Updated README.md
    Updated calibration video tag to indicate it is outdated. Added an embedded picture near the top to show final result.
2022-10-29 Added More Finished Pictures
    Added two pictures showing the fully assembled and complete joystick (left-handed, with throttle assembly). One used in README.md
